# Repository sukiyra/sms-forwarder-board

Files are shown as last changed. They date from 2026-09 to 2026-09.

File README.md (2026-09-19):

# SMS Forwarder Board

面向 ESP32-C3 与 ML307 系列蜂窝模组的短信网关固件、Web 管理台和 Windows 批量量产工具。

这是由 [sukiyra](https://github.com/sukiyra) 独立维护和发布的工程仓库，GitHub 仓库本身不是 Fork。固件、管理台、设备自检协议、版本发布和量产流程在同一个仓库维护。

## 主要能力

- 自动识别 ML307A、ML307C、ML307R、ML307Y，并按模组能力选择短信上报方式。
- 国内版 ML307C 可在移动、联通、电信网络注册；本产品的短信收发只承诺中国移动和中国联通，电信网络仍可用于数据连接但界面会明确标记短信不可用。
- 支持实体 SIM 与 eSIM/eUICC；白卡初始化错误会自动容错，首页分别显示卡识别、短信配置和蜂窝注册状态。
- 接收和主动发送短信；短信使用固定 50 条循环存储，不会无限占用 Flash。
- 支持企业微信、飞书、Bark、电子邮件、钉钉、PushPlus、Server 酱、Gotify、Telegram 及自定义 HTTP 推送。
- 可扫描运营商、严格手动选网和恢复自动选网；目标网络拒绝时自动恢复可用网络。
- 初始化引导自动扫描附近 Wi-Fi，可选择网络、输入密码并在保存前测试连接；系统设置中也可随时更换主备网络。
- Wi-Fi 断线时自动保活并轮询主备网络；持续无法恢复会自动开启 `sms-forwarder` 热点进入手动配网。
- 人可读通知统一显示北京时间；开放 API 与本地记录继续使用 UTC ISO-8601，便于程序可靠解析和排序。
- 响应式 Web 管理台，适配手机、普通桌面和超宽屏；仪表盘并列显示蜂窝与 Wi-Fi 五级信号图，跨页面保留 OTA、选网、切卡和短信发送进度。
- 设备健康面板实时显示堆内存占用、启动以来最低余量、最大连续内存块、碎片率、LittleFS 占用、运行时间和上次复位原因；低内存、严重碎片或存储异常会标红。
- Windows 量产工具支持在线选择 GitHub Release 版本、多串口并行烧录和逐台验收。
- Windows 局域网发现工具可自动列出同网段设备，并一键打开对应管理页面。
- 支持从 GitHub Releases 在线检查和安装 OTA 更新；通过资产 API 绕过部分网络对 GitHub 下载页的连接限制，分段下载时持续回报字节数和进度，并使用双应用分区、HTTPS 证书校验、SHA-256 校验与启动失败自动回滚。
- 每台设备输出 CSV 与 JSON 量产记录，不记录短信正文、Wi-Fi 密码或推送密钥。

## 下载与烧录

打开仓库的 [Releases](https://github.com/sukiyra/sms-forwarder-board/releases)，每个版本提供三个压缩包和一个 OTA 固件：

- `sms-forwarder-firmware-vX.Y.Z.zip`：带 SHA-256 清单的 ESP32-C3 固件。
- `sms-forwarder-production-tool-windows-vX.Y.Z.zip`：Windows 单文件量产工具与 `esptool.exe`。
- `sms-forwarder-lan-scanner-windows-vX.Y.Z.zip`：自动发现局域网设备并打开管理台。
- `sms-forwarder-ota-vX.Y.Z.bin`：设备在线升级使用的应用镜像。

普通用户只需下载 Windows 工具包并解压：

1. 双击 `sms-forwarder-production-tool.exe`。
2. 在“GitHub 版本”中选择要烧录的版本。
3. 插入一块或多块设备，点击“刷新串口”。
4. 选择设备后开始烧录。
5. 只把显示 `PASS` 的设备作为通过品。

在线固件会缓存在 `%LOCALAPPDATA%\SMS Forwarder Production Tool\firmware`。工具会验证 Release 压缩包结构、清单版本和每个镜像的 SHA-256；断网时可以切换到本地固件目录。

## 局域网设备发现

升级到 v1.6.0 或更高版本后，解压并运行 `sms-forwarder-lan-scanner.exe`。工具会扫描电脑的 IPv4 局域网，列出设备 IP、固件版本、模组型号、OTA 能力、MAC 和设备 ID；双击设备即可打开管理台。

发现协议使用 UDP 37888 和每次扫描生成的随机 nonce。设备只回应同一子网请求，并限制回复频率。报文不包含手机号、ICCID、短信、Wi-Fi 密码、登录密码或推送密钥。路由器开启 AP 隔离或访客网络隔离时，设备之间无法互相发现。

## 支持的硬件

| 部件 | 要求 |
| --- | --- |
| 主控 | ESP32-C3，4 MB Flash |
| 开发板配置 | MakerGO ESP32 C3 SuperMini |
| 蜂窝模组 | ML307A / ML307C / ML307R / ML307Y AT 固件 |
| 串口 | ESP32 GPIO3 → ML307 RX；GPIO4 ← ML307 TX |
| 模组使能 | ESP32 GPIO5 → ML307 EN |
| 供电 | 需满足模组发射瞬时电流，主控与模组共地 |

不同 ML307 完整料号支持的频段和运营商不同。固件能够适配 AT 指令差异，但不能为硬件增加缺失的射频频段。采购和量产前必须按完整丝印、模组规格书、SIM 套餐及当地网络实测。

## 首次启动

设备没有可用 Wi-Fi 配置时会开启 `sms-forwarder` 配置热点。连接后访问 `http://192.168.4.1`，初始化引导会自动扫描附近网络；选择 Wi-Fi、输入密码并完成连接测试后保存。设备接入局域网后，通过路由器分配的 IP 打开管理台。

运行期间断线时，设备先使用 ESP32 自动重连保活。持续 2 分钟仍未恢复会按顺序非阻塞尝试最多 5 个已保存网络，每个网络最多等待 12 秒；全部失败后自动恢复 `sms-forwarder` 配置热点。此时重新连接热点即可修改 Wi-Fi，不需要清空其他系统配置。

默认管理员账号为 `admin`，初始密码为 `admin123`。首次登录后请立即在“系统设置”中修改密码。管理页面使用局域网 HTTP，不应直接映射到公网。

## 手动编译

需要 Arduino CLI、ESP32 Arduino Core 3.3.11，以及以下库：

- `pdulib@0.5.11`
- `ReadyMail@0.4.2`
- `ArduinoJson@7.4.2`

PowerShell：

```powershell
arduino-cli compile `
  --fqbn esp32:esp32:makergo_c3_supermini `
  --build-property upload.maximum_size=1966080 `
  --output-dir .\build `
  .\code
```

仓库内的 `code/partitions.csv` 定义 4 MB Flash 双应用分区：`app0` 与 `app1` 各 1,920 KB，并保留 NVS、OTA 状态、128 KB LittleFS 短信存储和 64 KB 崩溃转储分区。不要用 Arduino 菜单中的单应用分区覆盖它。

## 在线 OTA

在“系统设置 → 在线固件升级”中检查并安装正式版。设备只接受本仓库最新 GitHub Release 中名称为 `sms-forwarder-ota-vX.Y.Z.bin` 的资产，并验证以下条件：

- HTTPS 证书链有效，设备时间已通过 NTP 同步。
- 目标版本高于当前版本，不允许在线降级。
- 文件名称、Content-Length、Release 资产大小和备用分区容量一致。
- 下载完成后的 SHA-256 与 GitHub Release 资产摘要一致。
- ESP32 镜像头和写入完整性通过 Update/bootloader 校验。

固件始终写入非活动分区。下载中断、摘要不符或写入失败不会切换启动分区；新版本首次启动必须完成配置、WiFi、Web 服务和模组初始化，之后才会确认镜像。此前发生崩溃或看门狗复位时，bootloader 会回滚到旧版本。

短信记录固定为 50 条循环存储，系统日志固定为 80 条且每条最多 320 字节，运营商扫描、长短信和任务队列也使用固定容量。管理台的健康面板会保留 ESP32 自启动以来的最低空闲堆指标，用于发现缓慢泄漏；量产和长期运行仍应使用实际电源、SIM 与网络做持续老化测试。

从旧分区升级时，必须先用当前量产包通过 USB 完整烧录一次分区表。只写入应用 BIN 或从已装在旧分区上的 v1.6.3 在线升级，都会保留旧分区表，无法创建 LittleFS；管理台会明确显示“分区需迁移”。完成这次迁移后，后续版本可直接在线升级。需要保留现有配置时，在量产工具中关闭“全片擦除”；NVS 地址保持不变。

## 量产工具命令行

```powershell
# 查询 GitHub 可烧录版本
python .\factory\production_tool.py --list-versions

# 选择指定 Release，并烧录所有自动识别的 ESP32 串口
python .\factory\production_tool.py --all --version v1.6.0 --require-sim --require-network

# 使用最新 Release，保留设备已有配置
python .\factory\production_tool.py --ports COM3 --version latest --keep-data

# 只运行工厂自检
python .\factory\production_tool.py --ports COM3 --skip-flash --require-sim --require-network
```

更多操作见 [量产工具说明](factory/README.md)。协议与模块结构见 [开发文档](dev_doc/README.md)。

## 发布流程

推送 `v*` 标签会自动执行：

1. Python 与 C++ 测试。
2. 嵌入式 JavaScript 语法检查。
3. ESP32-C3 固件编译。
4. 固件清单、USB 烧录 ZIP 与 OTA 应用镜像打包。
5. Windows 单文件量产工具和局域网发现工具构建。
6. 创建 GitHub Release 并上传固件包、OTA 镜像、量产工具和局域网发现工具。

## 许可证与来源

固件、Web 管理台和量产工具使用 [MIT License](LICENSE)。新仓库由 sukiyra 独立维护；早期 MIT 代码的版权声明和来源记录保存在 [NOTICE](NOTICE) 中。提交修复和功能前请确保不包含 SIM 完整 ICCID、手机号、Wi-Fi 密码或推送密钥。

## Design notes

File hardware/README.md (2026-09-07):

# SMS Forwarder Board Rev 1.0

这是与本仓库固件配套的 USB 棒形短信转发硬件。主控为 ESP32-C3-MINI-1，蜂窝模组为 ML307A-DSLN；ML307A-DCLN 可作为不需要 GNSS 时的替代料。工程使用 KiCad 10 创建，制造文件按立创/JLCPCB 四层板工艺导出。

Rev 1.0 是等待首板验证的工程样板。KiCad 10.0.6 ERC 与 DRC 均为 0 错误、0 警告、0 未连接，但这不能替代实体板的电源瞬态、射频、热、SMT 焊接和运营商网络测试。建议先下单 5 块裸板、贴装 2 块，完成 [装配与验证步骤](ASSEMBLY.md) 后再量产。

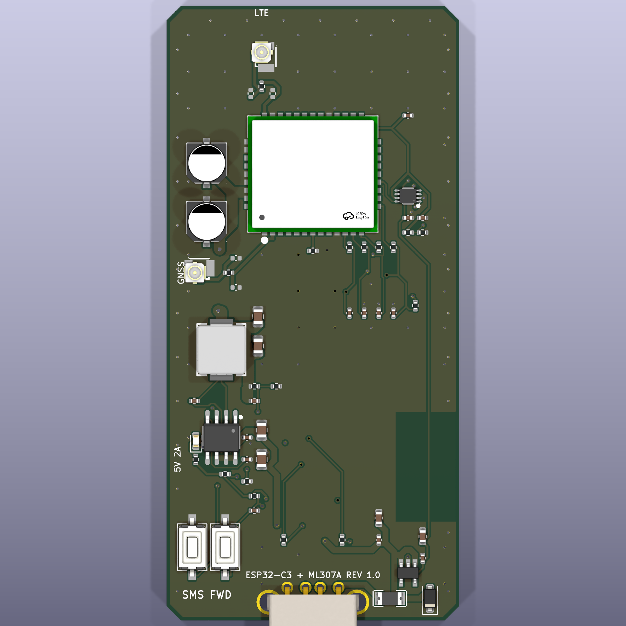
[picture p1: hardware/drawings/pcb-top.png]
PCB 正面


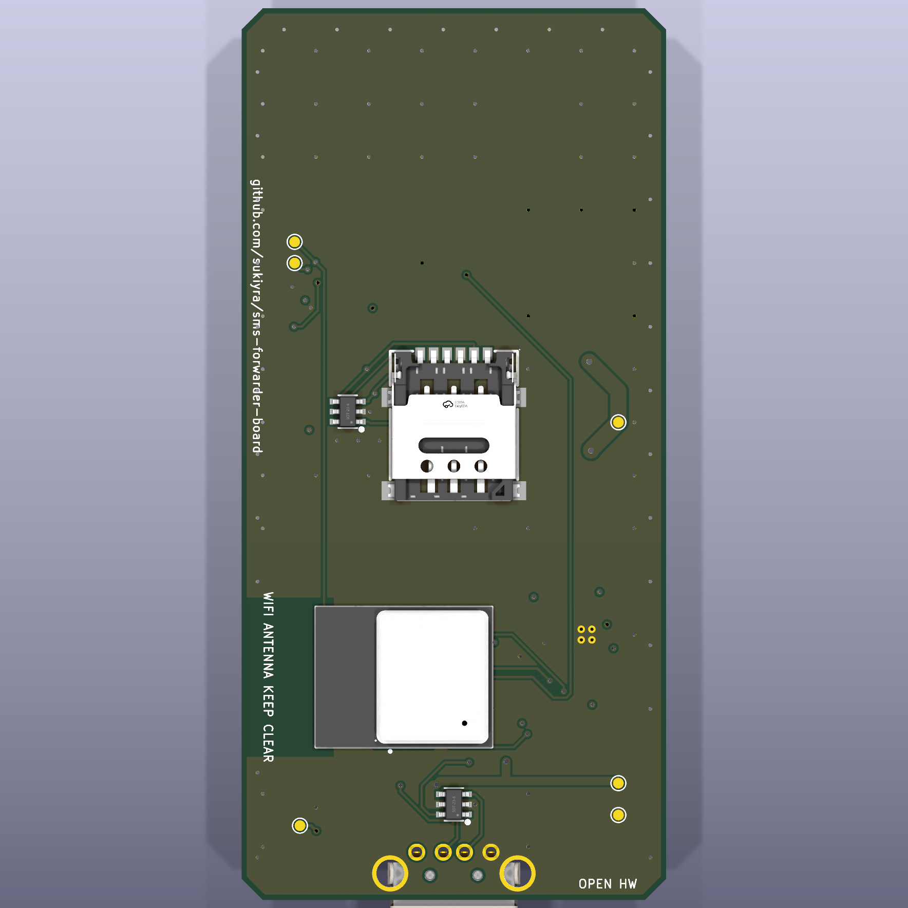
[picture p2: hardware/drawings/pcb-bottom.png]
PCB 背面


## 主要特性

- 40 mm × 84 mm 四层 PCB，USB-A 直插供电与原生 USB 下载。
- ESP32-C3 GPIO3/GPIO4 通过 TXU0202 与 ML307 的 1.8 V UART0 相连。
- ESP32-C3 GPIO5 控制 SY8205 的 EN，实现固件需要的模组硬断电重启。
- ML307 独立 3.816 V 同步降压电源，模组旁配置 2 × 220 µF 低 ESR 储能电容。
- Nano SIM 卡座、四路 SIM ESD、22 Ω 串联阻尼及 DATA 上拉。
- LTE MAIN 与可选 GNSS 两个 U.FL 接口，均预留 π 型匹配位。
- RESET、BOOT 按键和量产测试点。

## 文件目录

| 文件 | 用途 |
| --- | --- |
| `sms_forwarder_ml307a/` | KiCad 10 原理图、PCB、工程文件和 Specctra DSN |
| `libs/` | 项目专用符号、封装与 3D 模型 |
| `manufacturing/SMS-Forwarder-ML307A-Gerber.zip` | 可上传到立创下单页的 Gerber/钻孔压缩包 |
| `manufacturing/bom/BOM_JLCPCB.csv` | 立创 SMT BOM |
| `manufacturing/bom/BOM_Full.csv` | 含 DNP、手焊件与测试焊盘的完整 BOM |
| `manufacturing/bom/SMS-Forwarder-BOM.xlsx` | 便于采购、替代料和备注管理的 BOM |
| `manufacturing/pick-and-place/CPL_JLCPCB.csv` | JLC 标准列名的双面贴片坐标 |
| `drawings/schematic.pdf` | 原理图 PDF |
| `drawings/pcb-layout.pdf` | PCB 顶层装配图 |
| `tools/generate_hardware.py` | 重新生成器件布局、网表、DSN 与 BOM |

## 模组兼容性

本 PCB Rev 1.0 的焊盘仅适用于 **ML307A 94-pin 封装**。ML307C 与 ML307Y 使用 109-pin LCC+LGA 封装，虽然固件能够在运行时识别 A/C/Y 并选择兼容 AT 指令，但它们不能直接焊到本版 ML307A 焊盘上。C/Y 需要单独的 109-pin PCB 变体，不能通过软件解决封装差异。

这一区分也适用于量产：在贴片订单里必须把 `ML307A-DSLN / C5375091` 或 `ML307A-DCLN / C5362285` 与 PCB 版本绑定，不能让工厂按库存替换成 ML307C/Y。

## 立创下单参数

- 板层：4 层
- 板厚：1.6 mm
- 外层铜厚：1 oz
- 内层铜厚：0.5 oz
- 推荐叠层：JLC04161H-7628
- 阻抗：LTE/GNSS 走线按 50 Ω 单端复核；USB D+/D− 按 90 Ω 差分复核
- 表面处理：沉金 1U" 或无铅喷锡
- 阻焊/丝印：绿色/白色
- 最小信号线宽/间距：0.20/0.18 mm；局部接地扇出 0.15 mm
- 最小过孔：0.60/0.30 mm；模组电源过孔 1.00/0.50 mm
- 拼板：首轮不要拼板，先做 5 片工程样板

下单时选择与工程一致的阻抗叠层，并在阻抗计算器中重新确认最终线宽。立创可能调整材料批次或阻抗补偿，制造端给出的补偿值优先于工程中的名义线宽。

`BOM_JLCPCB.csv` 和 `CPL_JLCPCB.csv` 可直接用于 SMT 询价。USB-A 插头 J1 标为手焊件，RF 匹配电容 C23–C26 标为 DNP，测试点不会出现在贴片坐标中。立创导入后仍要逐项核对器件方向，特别是 U1、U2、J2、D1、D2、U3、U5、U6 和 U7。

## 供电要求

ML307 在 LTE 发射时会产生接近 2 A 的峰值电流。USB 电源必须能持续提供 5 V/2 A，并使用低阻 USB 接口或短延长线。普通电脑 USB 2.0 端口可能限流，表现为模组掉线、收不到短信、来电提示关机或反复注册。

板上 2 A 自恢复保险用于故障保护，不代表任意电脑 USB 端口都能提供 2 A。调试时应在 `TP1/+5V` 和 `TP2/+3V8_MODEM` 测量最低电压；模组发射期间 3.8 V 电源不能跌破 3.4 V。

## 首板验证

首批仅贴装 2 片，按 [装配与验证步骤](ASSEMBLY.md)逐项验收。通过电源纹波、UART、电流峰值、SIM、三网驻网、收发短信、Wi-Fi 和 24 小时压力测试后，再放开批量贴片。

## 重新生成

安装 KiCad 10 后运行 `hardware/tools/generate_hardware.py` 可重新生成放置完成的 PCB、DSN 和 CSV BOM。使用 Freerouting 1.6.5 对 DSN 布线后，以 `hardware/tools/import_freerouting.py` 导回 KiCad，再运行 `hardware/tools/generate_schematic.py` 和 KiCad CLI 导出制造资料。仓库内提交的 `.kicad_pcb` 已包含最终布线，不需要为了下单重新运行生成脚本。

## 许可证

`hardware/` 下的硬件源文件与制造资料使用 [CERN-OHL-P-2.0](LICENSE-CERN-OHL-P-2.0.txt)。仓库其余固件和量产工具继续使用根目录 MIT License。

## 设计依据

- [Espressif ESP32-C3 硬件设计指南](https://documentation.espressif.com/esp-hardware-design-guidelines/en/latest/esp32c3/index.html)
- [ESP32-C3-MINI-1/-1U 数据手册](https://documentation.espressif.com/esp32-c3-mini-1_datasheet_en.html)
- [JLCPCB 四层阻抗叠层](https://jlcpcb.com/impedance)
- ML307A Hardware Design Manual V1.0.1（仓库不再分发供应商手册；请从模组供应商取得当前版本）

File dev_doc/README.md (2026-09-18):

# 短信转发器 (SMS Forwarding) — 项目总览

## 项目简介

基于 **ESP32-C3 (MakerGO SuperMini)** 的短信转发设备。通过 4G/LTE 模组接收短信，经由 WiFi 网络将短信内容推送到邮件和多种即时通讯平台（微信/钉钉/飞书/Telegram 等）。提供 Web 管理界面进行配置和诊断。

现场故障与已验证处理方法统一记录在 [troubleshooting.md](troubleshooting.md)。

## 硬件平台

| 组件 | 型号 / 规格 |
|---|---|
| MCU | ESP32-C3 (MakerGO SuperMini) |
| 4G 模组 | 通过 UART 连接，AT 指令控制 |
| 模组 EN 引脚 | GPIO 5 |
| 模组 TXD/RXD | GPIO 3 / GPIO 4 |
| LED | GPIO 8（内置 LED） |
| 串口波特率 | USB: 115200, 模组: 115200 |

## 第三方依赖库

| 库 | 版本 | 用途 |
|---|---|---|
| pdulib | 0.5.11 | PDU 格式短信编解码 |
| ReadyMail | 0.4.2 | SMTP 邮件发送 |
| Arduino ESP32 Core | 3.3.11 | WiFi / HTTP / mbedTLS / NTP |

## 核心功能

1. **短信接收** — 4G 模组 PDU 模式自动上报，解析后提取发送方、设备接收时间、接收 Profile 与内容
2. **长短信合并** — 支持多段长短信（最多 10 段）自动拼合，30 秒超时保护
3. **多通道推送** — 同时支持最多 5 个推送通道，可独立配置推送到不同平台
4. **邮件通知** — 通过 SMTP 发送通知邮件（QQ 邮箱等）
5. **Web 管理** — 单页应用 (SPA)，侧边栏导航 + HTTP Basic Auth 保护
6. **系统日志** — Web 端实时查看设备串口日志，自动刷新，最多保留 80 行且单行最多 320 字节
7. **管理员命令** — 通过短信远程执行 SMS:发送 和 RESET 命令（仅限管理员号码）
8. **号码黑名单** — 支持按号码过滤骚扰短信

## 支持推送平台

| 类型 | 枚举值 | 说明 |
|---|---|---|
| POST JSON | `PUSH_TYPE_POST_JSON` (1) | 通用 POST JSON，字段: sender / message / timestamp |
| Bark | `PUSH_TYPE_BARK` (2) | iOS 推送，字段: title / body |
| GET 请求 | `PUSH_TYPE_GET` (3) | 参数放在 URL query string |
| 钉钉机器人 | `PUSH_TYPE_DINGTALK` (4) | 支持加签安全验证 |
| PushPlus | `PUSH_TYPE_PUSHPLUS` (5) | 微信公众号推送，支持多渠道 |
| Server酱 | `PUSH_TYPE_SERVERCHAN` (6) | 微信推送 |
| 自定义模板 | `PUSH_TYPE_CUSTOM` (7) | 用户自定义 HTTP 请求体 |
| 飞书机器人 | `PUSH_TYPE_FEISHU` (8) | 支持签名验证 |
| Gotify | `PUSH_TYPE_GOTIFY` (9) | 自建推送服务 |
| Telegram | `PUSH_TYPE_TELEGRAM` (10) | Bot API |
| 企业微信机器人 | `PUSH_TYPE_WECOM` (11) | 群机器人 Webhook，支持可选关键词 |

## 工程结构

```
code/
├── code.ino              # 入口: setup() + loop()
├── config_types.h        # 枚举/结构体/常量定义（无依赖）
├── globals.h / .cpp      # 全局变量 + 引脚定义 + 公共头文件
├── config.h / .cpp       # NVS 配置存取、配置校验
├── auth.h / .cpp         # Cookie 会话、CSRF 防护、登录限流
├── api_handlers.h / .cpp # 状态、短信、eSIM、运营商与配置 API
├── modem.h / .cpp        # 模组 AT 指令、电源控制、短信发送
├── push.h / .cpp         # 多通道推送、邮件通知、加密工具函数
├── sms_process.h / .cpp  # 短信解析、长短信合并、黑名单、管理员命令
├── sms_store.h / .cpp    # LittleFS 短信持久化与收件箱
├── esim_manager.h / .cpp # eUICC Profile 枚举、切换任务、EID 读取与删除（通道三级降级）
├── operator_manager.*    # 异步扫描、手动选网与自动选网任务
├── web_handlers.h / .cpp # HTTP 请求处理器 + 日志环形缓冲区
├── web_html.h / .cpp     # SPA HTML 页面模板（单页 10 个面板）
├── discovery.h / .cpp    # UDP 37888 局域网设备发现
├── ota_manager.h / .cpp  # GitHub Release 在线升级、摘要校验与回滚确认
├── ota_policy.h / .cpp   # 可在主机测试的版本与资产校验策略
└── partitions.csv        # 4 MB Flash 双 OTA 分区表
```

## 编译与烧录

```powershell
# 编译
arduino-cli compile --fqbn esp32:esp32:makergo_c3_supermini --build-property upload.maximum_size=2031616 --output-dir ".\build" ".\code"

# 烧录
arduino-cli upload --fqbn esp32:esp32:makergo_c3_supermini --port COM3 --input-dir ".\build" ".\code"

# 串口监视
arduino-cli monitor --port COM3 --config 115200
```

## 启动流程

1. 初始化 GPIO（LED、模组 EN 引脚）
2. 启动 USB Serial (115200) 和模组 Serial1 (115200, GPIO 3/4)
3. 模组断电重启（EN 引脚控制）
4. 加载 NVS 配置并挂载 LittleFS 短信存储
5. 连接 Wi-Fi，启动 HTTP 管理台并同步 NTP 时间
6. 若配置有效，发送启动通知邮件
7. 模组初始化：AT 握手 → 禁用数据连接 → 读取并脱敏缓存 ICCID 尾号 → 配置短信 URC 上报 → 设置 PDU 模式 → 等待网络注册
8. 启动 eSIM 与运营商状态管理任务

## 主循环

```
loop()
  ├── server.handleClient()     // HTTP 请求处理
  ├── 配置无效时每秒打印 IP
  ├── checkConcatTimeout()      // 长短信超时检查
  ├── Serial → Serial1 透传    // USB → 模组 AT 透传
  └── checkSerial1URC()        // 模组 URC 解析（短信上报）
```

## 关键设计决策

- **PDU 模式** 而非 Text 模式：中文短信必须使用 PDU 编码
- **CGACT 默认关闭**：启动时主动禁用 4G 数据连接，避免意外流量消耗（Ping 功能会临时激活）
- **NVS 持久化**：所有配置存储在 ESP32 非易失存储中，断电不丢失
- **单页应用 (SPA)**：Web UI 采用侧边栏 + 面板切换，所有功能在一个 HTML 页面中，通过 JS 切换可见面板
- **日志行缓冲**：`logCapture()` 将输出追加到行缓冲区，仅 `logCaptureLn()` 提交整行到环形缓冲区，避免非换行输出被误拆成多行
- **日志环形缓冲区**：80 行容量、单行 320 字节上限，循环覆盖，通过 `/log` 端点以 JSON 返回，Web 端每 2 秒自动刷新
- **模块化设计**：每个 .h/.cpp 对承担单一职责，便于增减功能和问题定位
- **HTML 模板分离**：HTML 字符串常量单独存于 `web_html.cpp`，便于 UI 修改而不影响逻辑代码

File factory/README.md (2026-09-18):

# Windows 批量量产工具

量产工具用于在线选择 GitHub Release 固件、并行烧录多块 ESP32-C3，并通过 USB 工厂协议验收 ESP32、ML307、SIM、短信配置和蜂窝注册。空板默认使用无卡硬件验收；插入测试卡后可额外要求短信和驻网通过。国内版 ML307C 使用电信网络时，“有卡验收：要求短信就绪”会判定短信能力不合格；移动和联通可正常进入短信验收。

## 直接使用发布包

1. 从 [GitHub Releases](https://github.com/sukiyra/sms-forwarder-board/releases) 下载 `sms-forwarder-production-tool-windows-vX.Y.Z.zip`。
2. 解压整个压缩包。
3. 双击 `sms-forwarder-production-tool.exe`。
4. 等待“GitHub 版本”下拉框加载，选择要量产的版本。
5. 插入设备并刷新串口，可一次多选并行烧录。
6. 新焊空板保持两个“有卡验收”选项不勾选；需要测试 SIM、短信和驻网时，插入测试卡后再勾选相应项目。
7. 点击“开始所选设备”，只接收显示 `PASS` 的设备。

无卡硬件验收仍会检查 ESP32-C3、Flash 烧录、固件工厂协议、USB 串口和 ML307 完整型号。未插 SIM 时不会把短信接口、运营商和蜂窝注册列为失败项，也不会掩盖主控或模组识别故障。

工具从 `sukiyra/sms-forwarder-board` 的 Releases 下载包含 `firmware` 的 ZIP。下载后会校验压缩包路径、版本号、ESP32-C3 芯片类型以及清单内每个镜像的 SHA-256。

下载缓存位于：

```text
%LOCALAPPDATA%\SMS Forwarder Production Tool\firmware
```

GitHub 暂时不可用时，选择“本地固件目录”即可离线烧录。

## OTA 分区迁移

v1.6.3 起使用两个 1,920 KB 应用分区，并保留 128 KB LittleFS 与 64 KB 崩溃转储，支持管理台在线升级和启动失败回滚。旧分区版本必须先通过本工具完整写入一次 v1.6.3 或更高版本；仅上传应用 BIN 无法更新分区表。

迁移时需要保留 WiFi、推送和登录配置，可关闭“全片擦除”。NVS 的地址和大小没有变化。量产新板仍建议开启全片擦除。

## 擦除策略

- 开启“全片擦除”：清除旧 Wi-Fi、推送配置和短信记录，适合正式出厂。
- 关闭“全片擦除”：保留数据分区，适合返修或固件升级。

## 量产记录

记录保存在程序目录的 `records` 文件夹：

- `production.csv`：一行一台，可用 Excel 打开。
- 独立 JSON：保留该设备完整工厂自检结果。

记录包含芯片 ID、固件版本、ML307 完整料号、SIM 类型、ICCID 尾号和网络 PLMN，不包含短信正文、Wi-Fi 密码或推送密钥。

## 从源码启动

```powershell
.\factory\start.ps1
```

首次运行会安装固定版本的 `pyserial`。

## 命令行

```powershell
# 列出串口
.\factory\start.ps1 --list

# 列出 GitHub 版本
.\factory\start.ps1 --list-versions

# 在线选择指定版本量产
.\factory\start.ps1 --all --version v1.6.0 --require-sim --require-network

# 在线选择最新版本并保留配置
.\factory\start.ps1 --ports COM3 COM4 --version latest --keep-data

# 使用本地固件目录
.\factory\start.ps1 --ports COM3 --firmware-dir .\factory\dist

# 只验收已烧录空板（无需 SIM）
.\factory\start.ps1 --ports COM3 --skip-flash

# 只验收已烧录设备，并要求 SIM、短信和驻网通过
.\factory\start.ps1 --ports COM3 --skip-flash --require-sim --require-network
```

可用 `--github-repo owner/repository` 指定其他兼容仓库；Release 必须包含固件 ZIP，压缩包内必须有唯一的 `manifest.json`。

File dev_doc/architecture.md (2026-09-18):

# 系统架构

## 模块依赖关系

```
                    ┌─────────────────────┐
                    │    config_types.h    │  (枚举/结构体/常量，无依赖)
                    └─────────┬───────────┘
                              │
                    ┌─────────▼───────────┐
                    │     globals.h       │  (全局变量声明 + 公共头文件)
                    │     globals.cpp     │  (全局变量定义)
                    └─────────┬───────────┘
                              │
        ┌─────────┬───────────┼───────────┬───────────┐
        │         │           │           │           │
   ┌────▼───┐ ┌───▼────┐ ┌───▼────┐ ┌───▼────┐ ┌───▼────┐
   │config  │ │ modem  │ │ push   │ │sms_prc │ │web_hdl │
   │.h/.cpp │ │.h/.cpp │ │.h/.cpp │ │.h/.cpp │ │.h/.cpp │
   └────────┘ └───┬──┬─┘ └───┬─┬──┘ └───┬────┘ └───┬────┘
                  │  │       │ │        │          │
                  │  └───────┼─┼────────┘    ┌─────┘
                  │          │ └─────────────┘
                  │    ┌─────▼──────┐    ┌───▼────┐
                  │    │sms_process │    │web_html│
                  │    │  .h/.cpp   │    │.h/.cpp │
                  │    └────────────┘    └────────┘
         ┌────────▼─────────┐
         │    code.ino      │  (入口: setup + loop)
         │ (NVS)  │
         └──────────────────┘
```

箭头方向 = `#include` 依赖方向。`config_types.h` 是最底层，`code.ino` 是最顶层。

## 数据流总览

### 短信接收流程

```
4G模组 UART
    │
    ▼
checkSerial1URC()          [sms_process.cpp]
    │  逐行读取 Serial1
    │  识别 "+CMT:" 头
    │  接收 PDU hex 数据
    ▼
pdu.decodePDU()            [pdulib 库]
    │  提取 sender / SCTS / text
    │  提取长短信 concatInfo (refNumber, partNumber, totalParts)
    ▼
┌─[长短信? totalParts > 1]─┐
│                           │
▼ 是                     ▼ 否 (普通短信)
findOrCreateConcatSlot()    │
  → 缓存分段                │
  → 收齐后合并              │
  → assembleConcatSms()     │
         │                  │
         └──────┬───────────┘
                ▼
         processSmsContent()
           ├── 记录设备接收时间 + 接收 Profile 脱敏标签
           ├── isInNumberBlackList()? → 忽略
           ├── isAdmin()? → processAdminCommand()
           │                  ├── "SMS:号码:内容" → sendSMS()
           │                  └── "RESET" → resetModule() + ESP.restart()
           ├── sendSMSToServer()     [push.cpp]
           │     └── sendToChannel() × N
           └── sendEmailNotification()  [push.cpp]
```

### HTTP 请求流程

```
浏览器 (SPA 单页应用)
    │  侧边栏切换面板，所有功能在一个 HTML 页面
    │  JS 控制 panel 可见性，无需页面跳转
    ▼
server.handleClient()     [code.ino loop]
    │
    ▼
checkAuth()               [web_handlers.cpp]
    │  HTTP Basic Auth
    │  账号: config.webUser
    │  密码: config.webPass
    ▼
路由分发:
    GET  /         → handleRoot()        SPA 主页 (HTML 模板变量替换，含 10 个面板)
    GET  /tools    → handleRoot()        兼容旧链接，返回同一 SPA 页面
    GET  /sms      → handleRoot()        兼容旧链接，返回同一 SPA 页面
    GET  /api/status → handleApiStatus()  读取缓存的设备/SIM/蜂窝信号状态
    POST /save     → handleSave()        保存配置 → saveConfig() → 发邮件
    POST /sendsms  → handleSendSms()     网页发送短信 → sendSMS()
    POST /ping     → handlePing()        AT+CGACT=1 → MPING → AT+CGACT=0
    GET  /query    → handleQuery()       查询 ATI/CESQ/ICCID/CEREG 等
    GET  /flight   → handleFlightMode()  AT+CFUN 查询/切换飞行模式
    GET  /at       → handleATCommand()   透传 AT 指令到模组
    GET  /log      → handleLog()         返回环形缓冲区日志 (JSON 数组)
```

### 蜂窝信号采集

`simManagerLoop()` 在 SIM 与短信服务就绪后，每 10 秒异步发送一次
`AT+CESQ`。解析后的 LTE RSRP/RSRQ 保存在内存中，`GET /api/status`
只读取缓存，不会因网页每 3 秒轮询而占用短信 UART。缓存超过 45 秒，或 SIM
拔出/状态失效后，接口返回未知信号。

### 日志系统架构

```
业务代码调用:
    logCapture("目标号码: ");       → Serial.print() + 追加到 _logLine
    logCaptureLn(String(phone));    → Serial.println() + 提交 _logLine 到环形缓冲区
    logCaptureF("ref=%d\n", ref);    → Serial.print() + 以 \n 结尾时自动提交整行
         │
         ▼
    _logLine (行缓冲区)              // 累积 logCapture 调用直到 logCaptureLn 或 \n
         │
         ▼  logCaptureLn / logCaptureF(\n)
    _logAppend()                    // 写入环形缓冲区
         │
         ▼
    logBuffer[120]                  // 环形缓冲区，循环覆盖
         │
         ▼
    handleLog()                     // GET /log → JSON ["line1","line2",...]
         │
         ▼
    Web 日志面板                   // 每 2 秒自动轮询，终端风格深色主题
```

### 配置持久化流程

```
Web 表单提交 /save
    │
    ▼
handleSave()
    │  解析 POST 参数
    │  赋值到 config 全局结构体
    ▼
saveConfig()              [config.cpp]
    │  Preferences(NVS) 写入
    │  namespace: "sms_config"
    ▼
configValid = isConfigValid()  重新校验
    │
    ▼
sendEmailNotification()   发送 "配置已更新" 邮件
```

## 线程/任务模型

单线程事件循环（标准 Arduino 模型），所有操作在主 loop 中串行执行：

| 操作 | 频率 | 超时保护 |
|---|---|---|
| HTTP 请求处理 | 每帧 | 无（非阻塞） |
| 长短信超时检查 | 每帧 | 30s 超时自动转发不完整消息 |
| Serial→Serial1 透传 | 每帧 | 无（单字节读） |
| Serial1 URC 检查 | 每帧 | 逐行读取，无行则立即返回 |
| 配置无效告警 | 每秒 | 仅 configValid=false 时 |

## 内存管理

- ESP32-C3 可用内存：~327KB
- 全局变量占用：~43KB
- PDU 缓冲区：4096 字节（`pdu = PDU(4096)`）
- 长短信缓存：5 组 × 10 段，每段内容动态分配（`String`）
- 日志环形缓冲区：80 行 × String，单行硬上限 320 字节
- 日志行缓冲区：1 个有界 String（`_logLine`），用于合并 logCapture 输出
- 串口行缓冲：500 字节（`SERIAL_BUFFER_SIZE`）
- HTTP 响应在函数内栈分配，调用结束自动释放
- `/api/status` 报告当前/历史最低堆、最大连续块、碎片率、LittleFS 占用与复位原因；`health_policy` 使用固定阈值统一输出健康等级

## 关键硬件引脚

| 定义 | GPIO | 功能 |
|---|---|---|
| `TXD` | 3 | 模组 UART TX |
| `RXD` | 4 | 模组 UART RX |
| `MODEM_EN_PIN` | 5 | 模组 EN 使能（LOW=关机, HIGH=开机） |
| `LED_BUILTIN` | 8 | 板载 LED（LOW=亮） |

## 错误处理策略

- **模组 AT 无响应**：重试（最多 10 次），LED 闪烁指示
- **WiFi 连接失败**：阻塞等待，LED 闪烁
- **NTP 同步失败**：记录日志，后续推送使用设备时间
- **HTTP 推送失败**：记录错误码和响应内容，不重试（避免卡顿）
- **PDU 解析失败**：记录日志，丢弃该条短信
- **长短信超时**：强制转发已收到的分段（标记缺失段）
- **配置无效**：每秒打印设备 IP 提示用户配置

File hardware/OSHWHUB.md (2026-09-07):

# 立创开源平台发布资料

## 项目标题

SMS Forwarder Board：ESP32-C3 + ML307A 4G 短信转发板

## 简介

一块 USB 棒形的 ESP32-C3 + ML307A Cat.1 短信转发器硬件。板上集成独立 3.8 V 同步降压模组电源、1.8 V UART 电平转换、Nano SIM、LTE/GNSS U.FL、USB 原生烧录与量产测试点，可直接运行本仓库的短信转发固件。

## 说明

本项目从器件数据手册与现有固件接口重新设计，提供 KiCad 源文件、Gerber、BOM、坐标文件、装配与首板验证说明。Rev 1.0 只适配 ML307A 94-pin 封装；ML307C/Y 为 109-pin 封装，需要单独 PCB 变体。

建议首轮打 5 片、只贴 2 片。ML307 发射峰值接近 2 A，必须使用 5 V/2 A 电源；普通电脑 USB 2.0 口限流时会导致掉网和短信异常。

当前 Rev 1.0 已通过 KiCad ERC/DRC，但尚未完成实体首板验证。发布状态应标记为“工程样板/待验证”，实体测试通过前不要标记为量产验证完成。

## 发布附件

- `sms_forwarder_ml307a.kicad_sch`、`sms_forwarder_ml307a.kicad_pcb`、`sms_forwarder_ml307a.kicad_pro`
- `SMS-Forwarder-ML307A-Gerber.zip`
- `BOM_JLCPCB.csv`、`BOM_Full.csv`、`SMS-Forwarder-BOM.xlsx`
- `CPL_JLCPCB.csv`
- `schematic.pdf`、`pcb-layout.pdf`、`pcb-top.png`、`pcb-bottom.png`
- `ASSEMBLY.md`、`NOTICE`、`LICENSE-CERN-OHL-P-2.0.txt`

## PCB 参数

40 × 84 mm、4 层、1.6 mm、外层 1 oz、内层 0.5 oz，推荐 JLC04161H-7628。最小孔 0.60/0.30 mm。LTE/GNSS 按 50 Ω 单端、USB 按 90 Ω 差分在下单阻抗计算器复核。

## 开源协议

CERN Open Hardware Licence Version 2 – Permissive（CERN-OHL-P-2.0）

## 标签

ESP32-C3、ML307A、Cat.1、短信转发、4G、Nano SIM、开源硬件、KiCad

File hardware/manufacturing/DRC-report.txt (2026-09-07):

** Drc report for sms_forwarder_ml307a.kicad_pcb **
** Created on 2026-09-07T19:52:12 **
** Report includes: Errors, Warnings **

** Found 0 DRC violations **

** Found 0 unconnected pads **

** Found 0 Footprint errors **

** Ignored checks **
    - Footprint has no courtyard defined
    - Track endpoint not centered on via
    - Tuning profile track geometries
    - Footprint doesn't match symbol's footprint filters
    - Footprint component type doesn't match footprint pads

** End of Report **

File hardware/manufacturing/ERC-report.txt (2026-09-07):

ERC report (2026-09-07T19:52:00, Encoding UTF8)
Report includes: Errors, Warnings

***** Sheet /

 ** ERC messages: 0  Errors 0  Warnings 0

 ** Ignored checks:
    - Global label only appears once in the schematic
    - Four connection points are joined together
    - SPICE model issue
    - Assigned footprint doesn't match footprint filters

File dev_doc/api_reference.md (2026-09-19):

# API 参考手册 — 完整函数索引

---

## 模块: config.cpp — 配置管理

### `void saveConfig()`
**用途**: 将 `config` 全局结构体所有字段写入 NVS。

**NVS Namespace**: `"sms_config"`
**写入模式**: `false`（读写模式）

**写入的 Key 列表**:
| NVS Key | 类型 | 对应字段 |
|---|---|---|
| `smtpServer` | String | `config.smtpServer` |
| `smtpPort` | Int | `config.smtpPort` |
| `smtpUser` | String | `config.smtpUser` |
| `smtpPass` | String | `config.smtpPass` |
| `smtpSendTo` | String | `config.smtpSendTo` |
| `adminPhone` | String | `config.adminPhone` |
| `webUser` | String | `config.webUser` |
| `webPass` | String | `config.webPass` |
| `numBlkList` | String | `config.numberBlackList` |
| `push{i}en` | Bool | 通道 i 是否启用 |
| `push{i}type` | UChar | 通道 i 推送类型 |
| `push{i}url` | String | 通道 i URL |
| `push{i}name` | String | 通道 i 名称 |
| `push{i}k1` | String | 通道 i 参数1 |
| `push{i}k2` | String | 通道 i 参数2 |
| `push{i}body` | String | 通道 i 自定义模板 |

---

### `void loadConfig()`
**用途**: 从 NVS 加载所有配置到 `config` 结构体。包含旧版本迁移逻辑。

**兼容迁移**: 如果存在旧 key `httpUrl` 且第一个推送通道未启用，自动迁移到通道 1。

**默认值**:
- `smtpPort`: 465
- `webUser`: `"admin"` (`DEFAULT_WEB_USER`)
- `webPass`: `"admin123"` (`DEFAULT_WEB_PASS`)
- 通道名称: `"通道1"` ~ `"通道5"`
- 通道类型: `PUSH_TYPE_POST_JSON` (1)

---

### `bool isPushChannelValid(const PushChannel& ch)`
**用途**: 检查单个推送通道配置是否完整可用。

**校验规则**:

| 推送类型 | 必填字段 |
|---|---|
| POST_JSON / BARK / GET / DINGTALK / FEISHU / CUSTOM | `url` 非空 |
| PUSHPLUS / SERVERCHAN | `key1` 非空 |
| GOTIFY | `url` 非空 **且** `key1` 非空 |
| TELEGRAM | `key1` 非空 **且** `key2` 非空 |

**前提**: `ch.enabled == true`，否则直接返回 false。

---

### `bool isConfigValid()`
**用途**: 检查系统是否有至少一种可用的通知方式。

**返回 true 条件**: 邮件配置完整（4 个 SMTP 字段均非空）**或** 至少一个推送通道通过 `isPushChannelValid()` 校验。

---

### `String getDeviceUrl()`
**返回**: `"http://{WiFi.localIP}/"`

---

## 模块: modem.cpp — 模组控制

### `String sendATCommand(const char* cmd, unsigned long timeout)`
**参数**:
- `cmd`: AT 指令字符串（不含 `\r\n`，函数自动追加）
- `timeout`: 等待超时（毫秒）

**行为**:
1. 清空 Serial1 缓冲区
2. 发送 `cmd\r\n`
3. 等待直到收到 "OK" 或 "ERROR" 或超时
4. 收到 OK/ERROR 后额外 `delay(50)` 读取剩余数据

**返回**: 模组完整响应字符串（含 OK/ERROR）

---

### `void modemPowerCycle()`
**行为**:
1. 配置 `MODEM_EN_PIN` 为输出
2. 拉低 1200ms → 关闭模组
3. 拉高 6000ms → 开启模组并等待启动

**注意**: 调用后需清空 Serial1 缓冲区（该函数不自动清空）

---

### `void resetModule()`
**行为**:
1. 调用 `modemPowerCycle()`
2. 清空 Serial1
3. 循环 10 次尝试 `sendATandWaitOK("AT", 1000)`
4. 打印恢复结果

---

### `bool sendATandWaitOK(const char* cmd, unsigned long timeout)`
**与 sendATCommand 区别**: 仅返回 true/false，不做额外 delay。用于初始化流程中的幂等检查。

---

### `bool waitCEREG()`
**用途**: 轮询 `AT+CEREG?` 直到网络注册成功。

**注册状态码**:
- `1`: 已注册本地网络 → true
- `5`: 已注册漫游 → true
- `0,2,3,4`: 未注册 → false

**超时**: 单次轮询 2000ms（调用方在外层循环调用）

---

### `void blink_short(unsigned long gap_time = 500)`
**行为**: LED 亮 50ms → 灭 → 等待 `gap_time` ms。

---

### `bool sendSMS(const char* phoneNumber, const char* message)`
**流程**:
1. `pdu.setSCAnumber()` 使用默认短信中心
2. `pdu.encodePDU(phoneNumber, message)` 编码
3. 发送 `AT+CMGS=<pduLen>`
4. 等待 `>` 提示符（5 秒超时）
5. 发送 PDU 数据 + `Ctrl+Z` (0x1A)
6. 等待 OK/ERROR（30 秒超时）

**返回**: true=成功, false=PDU编码失败/无提示符/ERROR/超时

---

## 模块: push.cpp — 推送与邮件

### `void sendEmailNotification(const char* subject, const char* body)`
**前提检查**: SMTP 四个字段均非空，否则打印跳过日志。

**实现**:
1. 创建 `smtp.connect(server, port, callback)`
2. `smtp.authenticate(user, pass, readymail_auth_password)`
3. 构造 `SMTPMessage`，设置 from/to/subject/body/timestamp
4. `smtp.send(msg)`

**from 格式**: `"sms notify <user@example.com>"`
**to 格式**: `"your_email <receiver@example.com>"`
**timestamp**: 使用 `time(nullptr)`（需 NTP 已同步）

---

### `void sendSMSToServer(const char* sender, const char* message, const char* timestamp)`
**行为**:
1. 检查 WiFi 连接
2. 检查是否有启用的有效通道
3. 遍历所有通道，对每个有效通道调用 `sendToChannel()`
4. 通道间 delay(100ms)

---

### `void sendToChannel(const PushChannel& channel, const char* sender, const char* message, const char* timestamp)`
**核心推送函数**。根据 `channel.type` 分发到 10 种推送方式之一。每个 case 构建对应的 HTTP 请求（URL/Header/Body），使用 `HTTPClient` 发送，打印响应码和内容。

**签名相关**:
- 钉钉: `HMAC-SHA256(timestamp+"\n"+secret)` → Base64 → URLEncode → 追加到 URL
- 飞书: `HMAC-SHA256(timestamp+"\n"+secret)` → Base64 → 放入 JSON body

**占位符**: 自定义模板（PUSH_TYPE_CUSTOM）支持 `{sender}` `{message}` `{timestamp}` 占位符替换。

---

### `String urlEncode(const String& str)`
标准 URL 编码（空格 → `+`, 非字母数字 → `%XX`）

---

### `String jsonEscape(const String& str)`
JSON 字符串转义：`"` → `\"`, `\` → `\\`, `\n` → `\\n`, `\r` → `\\r`, `\t` → `\\t`

---

### `String dingtalkSign(const String& secret, int64_t timestamp)`
HMAC-SHA256(timestamp + "\n" + secret, secret) → Base64 → URLEncode

---

### `int64_t getUtcMillis()`
通过 `gettimeofday()` 获取 UTC 毫秒级时间戳，失败则回退 `time(nullptr) * 1000`

---

## 模块: sms_process.cpp — 短信处理

### `void initConcatBuffer()`
将 `concatBuffer[MAX_CONCAT_MESSAGES]` 全部标记为未使用，清空所有分段。

---

### `int findOrCreateConcatSlot(int refNumber, const char* sender, int totalParts)`
**查找逻辑**:
1. 遍历缓冲区，找已用且 refNumber+sender 匹配的槽位 → 直接返回
2. 遍历缓冲区，找未使用槽位 → 初始化并返回
3. 无空闲槽位 → 覆盖最老的槽位（按 firstPartTime 比较）

---

### `String assembleConcatSms(int slot)`
按顺序拼接 `concatBuffer[slot].parts[0..totalParts-1]`，缺失分段标记 `[缺失分段N]`

---

### `void clearConcatSlot(int slot)`
将该槽位所有字段复位。

---

### `void checkConcatTimeout()`
遍历所有使用中的槽位，若 `millis() - firstPartTime >= 30000ms`，强制合并转发不完整消息，并清空槽位。

---

### `String readSerialLine(HardwareSerial& port)`
逐字节读取串口，遇 `\n` 返回行，`\r` 跳过，超长行保护（超过 SERIAL_BUFFER_SIZE 归零），无完整行返回空串。

**注意**: 使用 `static` 缓冲区，仅适合单线程调用。

---

### `bool isHexString(const String& str)`
检查字符串是否全为十六进制字符 `[0-9A-Fa-f]`。

---

### `bool isInNumberBlackList(const char* sender)`
**匹配逻辑**: 逐行读取 `config.numberBlackList`（换行符分隔），支持 `+86` 前缀的模糊匹配：
- `+8613800138000` 匹配黑名单中的 `13800138000`
- `13800138000` 匹配黑名单中的 `+8613800138000`

---

### `bool isAdmin(const char* sender)`
比较发送者与 `config.adminPhone`，忽略 `+86` 前缀差异。

---

### `void processAdminCommand(const char* sender, const char* text)`
**支持命令**:
| 命令格式 | 行为 |
|---|---|
| `SMS:号码:内容` | 调用 `sendSMS()` 代发短信，邮件通知结果 |
| `RESET` | 发送通知邮件 → `resetModule()` → `ESP.restart()` |

---

### `bool processSmsContent(const char* sender, const char* text, const char* timestamp)`

`timestamp` 对新短信为设备收到首个 PDU 分段时生成的 UTC ISO-8601 时间；NTP 不可用时回退为短信中心 SCTS。企业微信等面向用户的通知文本会转换为北京时间，API 字段仍保留原始时间。接收卡来源优先使用当前 Profile 名称与脱敏 ICCID 尾号；Profile 缓存尚未加载时使用 SIM ICCID 尾号写入本地收件箱。

**处理顺序**:
1. `isInNumberBlackList()` → 忽略
2. `isAdmin()` + 命令格式检测 → `processAdminCommand()` → 不再发普通通知
3. `smsStoreAdd()` — 持久化发送方、接收 Profile、设备接收时间与正文
4. `sendSMSToServer()` — 推送所有启用的通道
5. `sendEmailNotification()` — 邮件通知

---

### `void checkSerial1URC()`
**状态机**: `IDLE` ↔ `WAIT_PDU`

IDLE 状态检测 `+CMT:` 行 → 转入 WAIT_PDU。
WAIT_PDU 状态读取 PDU hex 数据 → `pdu.decodePDU()` 解析 → 根据 `concatInfo` 判断长短信/普通短信 → 恢复 IDLE。

---

## 模块: api_handlers.cpp — JSON API

### `void handleApiStatus()`
**用途**: HTTP 端点 `GET /api/status`，返回仪表盘使用的实时设备状态。蜂窝信号来自 SIM 管理器异步缓存，不在 HTTP 请求中同步执行 AT 指令。

**蜂窝信号字段**:

```json
{
  "modem": {
    "rsrp": -93,
    "rsrq": -12.0,
    "signal": {
      "known": true,
      "metric": "RSRP",
      "dbm": -93,
      "raw": 47,
      "rsrq": -12.0,
      "updatedAt": 60089,
      "ageMs": 3043
    }
  }
}
```

`rsrp` 与 `signal.dbm` 的单位为 dBm，`rsrq` 的单位为 dB；`raw` 是
`AT+CESQ` 的 RSRP 原始编码。信号未知、采样超过 45 秒或 SIM 不可用时，数值
字段返回 `null` 且 `known` 为 `false`。

**设备健康字段**:

```json
{
  "health": {
    "state": "healthy",
    "heapTotal": 286156,
    "heapFree": 158704,
    "heapMin": 152132,
    "heapLargest": 114676,
    "heapUsedPercent": 45,
    "fragmentationPercent": 28,
    "partitionLayoutCompatible": true,
    "otaPartitionSize": 1966080,
    "expectedOtaPartitionSize": 1966080,
    "storageReady": true,
    "storageTotal": 131072,
    "storageUsed": 49152,
    "storageUsedPercent": 38,
    "resetReason": "power_on"
  }
}
```

`heapMin` 是本次启动以来的最低可用堆，`heapLargest` 是当前最大连续可分配块。
`state` 由 `health_policy` 根据空闲余量、历史最低值、连续块、碎片率和 LittleFS
状态统一计算，取值为 `healthy`、`warning` 或 `critical`。
`partitionLayoutCompatible` 用备用应用分区的实际容量识别旧分区表。该值为
`false` 时，OTA 只能更新应用，不能创建 LittleFS，必须使用 USB 完整烧录分区表。

## 模块: web_handlers.cpp — HTTP 处理

### 日志系统 API

### `void logCapture(const String& msg)`
### `void logCapture(const char* msg)`
**用途**: 输出日志，但不换行。内容追加到行缓冲区 `_logLine`，不会立即写入环形缓冲区。同时输出到 `Serial`。

**使用场景**: 与 `logCaptureLn()` 配合，构建一行完整日志：
```cpp
logCapture("目标号码: ");
logCaptureLn(String(phoneNumber));
// 环形缓冲区中只有一行: "目标号码: 13800138000"
```

---

### `void logCaptureLn(const String& msg)`
### `void logCaptureLn(const char* msg)`
**用途**: 输出日志并换行。将 `_logLine` + msg 提交到环形缓冲区，然后清空行缓冲区。同时输出到 `Serial.println`。

**注意**: 环形缓冲区每调用一次 `logCaptureLn` 即可产生一行日志，因此 `logCapture()` 和 `logCaptureLn()` 的日志会在环形缓冲区中合并为同一行。每行最多保留 320 字节，超出部分截断，避免异常模组输出持续扩大动态内存。

---

### `void logCaptureF(const char* fmt, ...)`
**用途**: 格式化日志输出（类似 `printf`）。支持 `%d`/`%s`/`%f` 等格式。如果格式化字符串以 `\n` 结尾，自动提交整行到缓冲区。

---

### `void handleLog()`
**用途**: HTTP 端点 `GET /log`，返回环形缓冲区中所有日志行。

**返回格式**: `application/json`
```json
["行1", "行2", "行3", ...]
```
**鉴权**: 需要有效管理会话。最多返回 80 行（环形缓冲区容量）。

---

### `bool checkAuth()`
HTTP Basic Authentication，账号密码来自 `config.webUser` / `config.webPass`。

---

### `void handleRoot()`
返回 SPA 主页 HTML。通过 `html.replace("%KEY%", value)` 替换模板占位符，动态生成 5 个推送通道的表单。页面包含 10 个可切换面板（系统概览/账号管理/邮件通知/推送通道/管理员黑名单/发送短信/模组诊断/网络测试/模组控制/AT终端/系统日志），通过侧边栏 JS 切换显示。

**模板占位符**:

| 占位符 | 数据来源 |
|---|---|
| `%IP%` | `WiFi.localIP().toString()` |
| `%WEB_USER%` / `%WEB_PASS%` | `config.webUser` / `config.webPass` |
| `%SMTP_SERVER%` ~ `%SMTP_SEND_TO%` | `config.smtp*` |
| `%ADMIN_PHONE%` | `config.adminPhone` |
| `%NUMBER_BLACK_LIST%` | `config.numberBlackList` |
| `%SMTP_CHECK%` | 邮件配置是否完整 |
| `%PUSH_COUNT%` | 已启用的有效推送通道数 |
| `%PUSH_CHANNELS%` | 循环生成 5 个通道的 HTML 表单 |

---

### `void handleToolsPage()`
兼容旧链接，直接委托给 `handleRoot()` 返回同一 SPA 页面。

---

### `void handleSave()`
解析 POST 表单 → 写入 `config` → `saveConfig()` → 重新校验 → 发送通知邮件 → 返回成功页面（3 秒跳转）。

---

### `void handleQuery()`
根据 `?type=` 参数执行不同查询：

| type | AT 指令 | 返回内容 |
|---|---|---|
| `ati` | `ATI` | 制造商/型号/固件版本 |
| `signal` | `AT+CESQ` | RSRP/RSRQ 信号强度 |
| `siminfo` | `AT+CIMI` `AT+ICCID` `AT+CNUM` | IMSI/ICCID/本机号码 |
| `network` | `AT+CEREG?` `AT+COPS?` `AT+CGACT?` `AT+CGDCONT?` | 注册/运营商/数据/APN |
| `wifi` | (WiFi 对象) | SSID/RSSI/IP/网关/DNS/MAC/BSSID/信道 |

---

### `void handleFlightMode()`
根据 `?action=` 控制飞行模式：

| action | AT 指令 | 说明 |
|---|---|---|
| `query` | `AT+CFUN?` | 查询当前 CFUN 值 |
| `toggle` | 查询 + `AT+CFUN=1/4` | 1↔4 切换 |
| `on` | `AT+CFUN=4` | 强制开启 |
| `off` | `AT+CFUN=1` | 强制关闭 |

---

### `void handleATCommand()`
通过 `?cmd=` 透传 AT 指令到 `sendATCommand()`，返回 JSON `{success, message}`。

---

### `void handleSendSms()`
解析 POST 表单 phone/content → 调用 `sendSMS()` → 返回 HTML 结果页（3 秒跳转）。

---

### `void handlePing()`
**流程**:
1. `AT+CGACT=1,1` 激活数据连接
2. `AT+MPING="8.8.8.8",30,1` ping 一次（30 秒超时）
3. 解析 `+MPING:` URC 响应，提取 IP/延迟/TTL
4. `AT+CGACT=0,1` 关闭数据连接
5. 返回 JSON `{success, message}`

**注意**: 整个操作最长约 35 秒。

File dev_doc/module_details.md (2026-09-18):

# 模块详解 — 逐文件源码指南

---

## code.ino — 主入口

**文件**: `code/code.ino` (约 105 行)
**角色**: Arduino 工程入口点，仅包含 `setup()` 和 `loop()`。

### setup() 初始化顺序

```
1. GPIO 初始化
   ├── pinMode(LED_BUILTIN, OUTPUT); digitalWrite(HIGH)   // LED 灭
   └── (MODEM_EN_PIN 在 modemPowerCycle 内设置)

2. 串口初始化
   ├── Serial.begin(115200); delay(1500)                   // USB CDC 稳定
   └── Serial1.begin(115200, SERIAL_8N1, RXD, TXD)        // 模组 UART

3. 模组上电
   ├── Serial1.read() 清噪声
   ├── modemPowerCycle()                                     // EN 引脚时序
   └── Serial1.read() 清启动噪声

4. 数据加载
   ├── initConcatBuffer()                                    // 长短信缓存清零
   ├── loadConfig()                                          // NVS → config
   └── configValid = isConfigValid()                        // 校验

5. 模组初始化 (AT 指令序列，每步失败重试+LED闪烁)
   ├── sendATandWaitOK("AT", 1000)                          // 握手
   ├── sendATandWaitOK("AT+CGACT=0,1", 5000)               // 禁数据(省流量)
   ├── sendATCommand("AT+ICCID", 2000)                      // 仅缓存接收卡尾号
   ├── sendATandWaitOK("AT+CNMI=2,2,0,0,0", 1000)          // 短信URC上报
   ├── sendATandWaitOK("AT+CMGF=0", 1000)                   // PDU模式
   └── waitCEREG()                                           // 等网络注册

6. WiFi 连接
   ├── WiFi.setScanMethod(WIFI_ALL_CHANNEL_SCAN)             // 扫描全部信道
   └── WiFi.begin(SSID, PASS, 0, nullptr, true)              // 支持隐藏SSID

7. NTP 时间同步
   ├── configTime(0, 0, "ntp.ntsc.ac.cn", ...)              // UTC时区
   └── 等待 time() > 100000 (最多10秒)

8. HTTP 服务器
   ├── server.on("/", handleRoot)
   ├── server.on("/save", HTTP_POST, handleSave)
   ├── server.on("/tools", handleRoot)                       # 兼容旧链接
   ├── server.on("/sms", handleRoot)                         # 兼容旧链接
   ├── server.on("/sendsms", HTTP_POST, handleSendSms)
   ├── server.on("/ping", HTTP_POST, handlePing)
   ├── server.on("/query", handleQuery)
   ├── server.on("/flight", handleFlightMode)
   ├── server.on("/at", handleATCommand)
   ├── server.on("/log", handleLog)                          # 系统日志 JSON
   └── server.begin()

9. 启动通知
   └── if(configValid) sendEmailNotification("短信转发器已启动", ...)
```

### loop() 执行顺序（每帧执行）

```cpp
server.handleClient();        // 1. 处理HTTP请求
if(!configValid) { ... }      // 2. 配置无效时每秒打印IP
checkConcatTimeout();          // 3. 长短信超时合并转发
if(Serial.available())        // 4. USB->模组透传(单字节)
    Serial1.write(Serial.read());
checkSerial1URC();             // 5. 检查模组URC(短信上报)
```

### 修改指南

- **新增 HTTP 路由**: 在 `web_handlers.h/.cpp` 添加处理函数，然后在 `setup()` 中 `server.on("/path", handler)`
- **调整初始化顺序**: 直接修改 `setup()` 中的代码顺序即可，注意模组初始化必须在 WiFi 之前
- **禁用某功能**: 注释掉对应的 `server.on()` 行即可

---

## config_types.h — 类型定义

**依赖**: 仅 `<Arduino.h>`
**被依赖**: 所有其他模块

### PushType 枚举 (0-10)

表示推送目标平台。值 0 为"未启用"，1-10 对应 10 种推送方式。

**添加新推送类型**:
1. 在 `PushType` 枚举末尾添加新值（如 `PUSH_TYPE_NEW = 11`）
2. 在 `isPushChannelValid()` 添加对应的必填字段校验
3. 在 `sendToChannel()` 添加 `case PUSH_TYPE_NEW:` 实现
4. 在 `handleRoot()` 的 HTML 生成中添加 option
5. 在 HTML JavaScript `updateTypeHint()` 中添加类型提示

### PushChannel 结构体

通用推送通道配置。字段含义:
- `enabled` — 开关
- `type` — PushType 枚举值
- `name` — WebUI 中显示的名称
- `url` — Webhook URL（GET 类型则为目标 URL）
- `key1` — 通用参数 1（token/secret/chat_id 等）
- `key2` — 通用参数 2（channel/bot_token 等）
- `customBody` — 自定义模板的 HTTP body

### Config 结构体

所有可持久化配置的容器，通过 `saveConfig()/loadConfig()` 与 NVS 同步。

### 常量

| 常量 | 值 | 说明 |
|---|---|---|
| `MAX_PUSH_CHANNELS` | 5 | 推送通道数量上限 |
| `MAX_CONCAT_PARTS` | 10 | 长短信最大分段数 |
| `CONCAT_TIMEOUT_MS` | 30000 | 长短信等待超时(ms) |
| `MAX_CONCAT_MESSAGES` | 5 | 同时缓存的长短信组数 |
| `DEFAULT_WEB_USER` | `"admin"` | 默认 Web 账号 |
| `DEFAULT_WEB_PASS` | `"admin123"` | 默认 Web 密码 |

---

## globals.h / globals.cpp — 全局变量

### 全局变量清单

| 变量 | 类型 | 初始化 | 用途 |
|---|---|---|---|
| `config` | `Config` | 默认构造 | 系统全部配置（运行时+持久化） |
| `preferences` | `Preferences` | 默认构造 | NVS 存储接口 |
| `pdu` | `PDU` | `PDU(4096)` | PDU 编解码器（4KB 缓冲区） |
| `ssl_client` | `WiFiClientSecure` | 默认构造 | TLS 客户端（SMTP/HTTPS） |
| `smtp` | `SMTPClient` | `SMTPClient(ssl_client)` | SMTP 邮件客户端 |
| `server` | `WebServer` | `WebServer(80)` | HTTP 服务器（端口 80） |
| `configValid` | `bool` | `false` | 配置是否有效标志 |
| `timeSynced` | `bool` | `false` | NTP 是否已同步 |
| `lastPrintTime` | `unsigned long` | `0` | 上次打印 IP 的 millis |
| `concatBuffer` | `ConcatSms[5]` | 默认构造 | 长短信合并缓存 |

### 功能说明

- **添加新的全局变量**: 在 `globals.h` 添加 `extern` 声明，在 `globals.cpp` 添加定义
- **添加新的库依赖**: 在 `globals.h` 添加 `#include`，所有模块自动获得该依赖

---

## config.h / config.cpp — 配置管理

### NVS 存储结构

```
Namespace: "sms_config"
├── smtpServer  (String)
├── smtpPort    (Int, 默认 465)
├── smtpUser    (String)
├── smtpPass    (String)
├── smtpSendTo  (String)
├── adminPhone  (String)
├── webUser     (String, 默认 "admin")
├── webPass     (String, 默认 "admin123")
├── numBlkList  (String, 换行分隔)
├── push0en     (Bool)
├── push0type   (UChar)
├── push0url    (String)
├── push0name   (String)
├── push0k1     (String)
├── push0k2     (String)
├── push0body   (String)
├── push1en ... (同上 × 4)
└── ...
```

### 兼容迁移机制

`loadConfig()` 末尾检查旧 key `httpUrl` 和 `barkMode`，若存在则自动迁移到 `pushChannels[0]`。这是旧版单通道配置 → 新版多通道配置的迁移路径。

### 修改指南

- **添加新配置项**: 在 `Config` 结构体加字段 → `loadConfig()` 加读取（设默认值） → `saveConfig()` 加写入 → `handleSave()` 加表单解析
- **修改校验逻辑**: 编辑 `isPushChannelValid()` 和 `isConfigValid()`

---

## modem.h / modem.cpp — 模组控制

### 串口通信模型

```
ESP32-C3                   4G 模组
  Serial1 (UART) ──────────── AT 端口
  GPIO 5     ──────────── EN 引脚
```

### AT 指令函数对比

| 函数 | 返回类型 | 延时处理 | 适用场景 |
|---|---|---|---|
| `sendATCommand()` | String (完整响应) | 收到 OK/ERROR 后 `delay(50)` | 需要解析响应内容 |
| `sendATandWaitOK()` | bool | 无额外 delay | 快速幂等检查 |

### 模组电源控制

```
modemPowerCycle():
  EN=HIGH (默认)  模组运行
      ↓
  EN=LOW (1200ms) 模组断电
      ↓
  EN=HIGH (6000ms) 模组上电启动
```

6000ms 是关键时间，太短模组初始化未完成会导致 AT 无响应。

### sendSMS() 时序图

```
ESP32                         模组
  │                            │
  ├─ AT+CMGS=<len>\r\n ──────►│
  │                            │
  │◄───────────────────── >  │  (提示符)
  │                            │
  ├─ PDU hex data + 0x1A ────►│
  │                            │
  │◄──────────────── +CMGS:   │  (成功响应)
  │◄──────────────── OK       │
```

### 修改指南

- **更换模组型号**: 修改 `modemPowerCycle()` 的时序参数，调整 AT 指令序列
- **添加新 AT 功能**: 实现新函数，使用 `sendATCommand()` 或直接操作 `Serial1`
- **调波特率**: 修改 `Serial1.begin()` 参数 + 模组 AT 配置

---

## push.h / push.cpp — 推送服务

### 推送通道执行流程

```
sendSMSToServer(sender, message, timestamp)
  │
  ├─ 检查 WiFi 连接
  ├─ 检查是否有启用的有效通道
  │
  └─ for each valid channel:
       └─ sendToChannel(channel, sender, message, timestamp)
            │
            ├─ jsonEscape() 转义 sender/message/timestamp
            │
            └─ switch(channel.type):
                 ├─ POST_JSON  → POST {sender, message, timestamp}
                 ├─ BARK       → POST {title, body}
                 ├─ GET        → GET ?sender=&message=&timestamp=
                 ├─ DINGTALK   → POST {msgtype:"text", text:{content:"..."}}
                 │               ├─ 有secret → dingtalkSign() 追加URL参数
                 ├─ PUSHPLUS   → POST {token, title, content, channel}
                 │               └─ 默认URL: http://www.pushplus.plus/send
                 ├─ SERVERCHAN → POST title=&desp= (form-urlencoded)
                 │               └─ 默认URL: https://sctapi.ftqq.com/{key1}.send
                 ├─ CUSTOM     → POST (使用 customBody 模板替换)
                 ├─ FEISHU     → POST {timestamp?, sign?, msg_type, content}
                 │               └─ 有secret → HMAC-SHA256签名
                 ├─ GOTIFY     → POST {title, message, priority}
                 │               └─ URL: {url}/message?token={key1}
                 └─ TELEGRAM   → POST {chat_id, text}
                     └─ 默认URL: https://api.telegram.org/bot{key2}/sendMessage
```

### HMAC 签名实现

钉钉和飞书都使用 `mbedtls_md` 库（ESP32 内置）:
```cpp
mbedtls_md_context_t ctx;
mbedtls_md_init(&ctx);
mbedtls_md_setup(&ctx, MBEDTLS_MD_SHA256, 1);
mbedtls_md_hmac_starts(&ctx, key, keyLen);
mbedtls_md_hmac_update(&ctx, data, dataLen);
mbedtls_md_hmac_finish(&ctx, hmacResult);
mbedtls_md_free(&ctx);
// hmacResult → base64::encode() → urlEncode()
```

### 邮件发送

使用 ReadyMail 库的 SMTP 客户端:
```cpp
smtp.connect(server, port, callback);
smtp.authenticate(user, pass, readymail_auth_password);
SMTPMessage msg;
msg.headers.add(rfc822_from, from);
msg.headers.add(rfc822_to, to);
msg.headers.add(rfc822_subject, subject);
msg.text.body(body);
msg.timestamp = time(nullptr);
smtp.send(msg);
```

### 修改指南

- **添加新推送通道**: 在 `PushType` 加枚举 → `isPushChannelValid()` 加校验 → `sendToChannel()` 加 case → Web UI 加选项
- **修改钉钉/飞书签名逻辑**: 编辑 `dingtalkSign()` 或 `sendToChannel()` 中 FEISHU case
- **更换 SMTP 库**: 只需修改 `sendEmailNotification()` 函数

---

## sms_process.h / sms_process.cpp — 短信处理

### 长短信合并状态机

```
┌─────────────────────────────────────────────────────┐
│                  concatBuffer[0..4]                  │
│  ┌─────────┐  ┌─────────┐      ┌─────────┐         │
│  │ Slot 0  │  │ Slot 1  │ ...  │ Slot 4  │         │
│  │ inUse   │  │ inUse   │      │ inUse   │         │
│  │ refNum  │  │ refNum  │      │ refNum  │         │
│  │ total   │  │ total   │      │ total   │         │
│  │ recv'd  │  │ recv'd  │      │ recv'd  │         │
│  │ time    │  │ time    │      │ time    │         │
│  │ parts[] │  │ parts[] │      │ parts[] │         │
│  └─────────┘  └─────────┘      └─────────┘         │
└─────────────────────────────────────────────────────┘
```

### PDU 解析流程

```
checkSerial1URC() 循环:
  ┌─ IDLE 状态 ──────────────────────────────────────┐
  │  逐行读取 Serial1                                 │
  │  检测 "+CMT:" → 转入 WAIT_PDU                    │
  └──────────────────────────────────────────────────┘
                       │
  ┌─ WAIT_PDU 状态 ──────────────────────────────────┐
  │  读取下一行                                       │
  │  isHexString()?                                   │
  │    ├─ 是 → pdu.decodePDU(line)                   │
  │    │       ├─ 失败 → 打印错误, 回 IDLE            │
  │    │       └─ 成功 → 提取 sender/text/timestamp   │
  │    │                → 检查 concatInfo              │
  │    │                  ├─ 长短信 → 缓存分段         │
  │    │                  │   └─ 收齐? → 合并→process │
  │    │                  └─ 普通短信 → process        │
  │    └─ 否 → 回 IDLE                               │
  └──────────────────────────────────────────────────┘
```

### 黑名单匹配算法

```
原始发送者号码: "+8613800138000"
  │
  ├─ 提取纯号码: "13800138000" (去+86)
  │
  └─ 逐行对比黑名单:
       黑名单行 "13800138000" → 匹配 ✓
       黑名单行 "13900139000" → 不匹配
       黑名单行 "+8613800138000" → 匹配 ✓ (用原始号码对比)
```

### 管理员命令解析

```
短信内容: "SMS:13800138000:你好世界"
  │
  ├─ 第一个 ':'  → "SMS"
  ├─ 第二个 ':'  → "13800138000"  (目标号码)
  └─ 剩余内容    → "你好世界"      (短信内容)
  │
  └─ sendSMS("13800138000", "你好世界")

短信内容: "RESET"
  └─ resetModule() + ESP.restart()
```

### 修改指南

- **调整长短信超时**: 修改 `CONCAT_TIMEOUT_MS` 宏（config_types.h）
- **修改黑名单匹配逻辑**: 编辑 `isInNumberBlackList()`
- **添加新管理员命令**: 在 `processAdminCommand()` 中添加 `else if` 分支
- **更换短信库**: 修改 `checkSerial1URC()` 中的 `pdu.decodePDU()` 调用

---

## web_handlers.h / web_handlers.cpp — HTTP 处理 + 日志系统

### 路由表

| 方法 | 路径 | 处理函数 | Auth | 说明 |
|---|---|---|---|---|
| GET | `/` | `handleRoot()` | ✓ | SPA 主页（含 10 个面板） |
| GET | `/tools` | `handleRoot()` | ✓ | 旧链接兼容，返回同一 SPA 页面 |
| GET | `/sms` | `handleRoot()` | ✓ | 旧链接兼容，返回同一 SPA 页面 |
| POST | `/save` | `handleSave()` | ✓ | 保存配置 |
| POST | `/sendsms` | `handleSendSms()` | ✓ | 网页发送短信 |
| POST | `/ping` | `handlePing()` | ✓ | Ping 测试 |
| GET | `/query` | `handleQuery()` | ✓ | 模组/WiFi 信息查询 |
| GET | `/flight` | `handleFlightMode()` | ✓ | 飞行模式控制 |
| GET | `/at` | `handleATCommand()` | ✓ | AT 指令调试 |
| GET | `/log` | `handleLog()` | ✓ | 系统日志（JSON 数组） |

### 日志环形缓冲区

```
容量: LOG_BUF_SIZE = 80 行，每行最多 320 字节
结构: String logBuffer[80] + 有界行缓冲 _logLine
写入:
  logCapture(msg)      → Serial.print() + 追加到 _logLine
  logCaptureLn(msg)    → Serial.println() + 提交 _logLine 到环形缓冲区
  logCaptureF(fmt,...) → Serial.print() + 追加到 _logLine (fmt 以 \n 结尾时自动提交)
读取:
  handlerLog()         → JSON ["行1","行2",...] (按插入顺序)
```

**行缓冲设计目的**: 避免 `logCapture("A:"); logCaptureLn(B);` 在环形缓冲区中产生两个独立条目。实际只产生一行 `"A: B"`。长度上限用于阻止连续异常输出造成动态内存持续增长。

### 模板变量替换

SPA 页面中的 `%PLACEHOLDER%` 在 `handleRoot()` 中通过 `html.replace()` 替换:

| 占位符 | 数据来源 |
|---|---|
| `%IP%` | `WiFi.localIP().toString()` |
| `%WEB_USER%` / `%WEB_PASS%` | `config.webUser` / `config.webPass` |
| `%SMTP_SERVER%` ~ `%SMTP_SEND_TO%` | `config.smtp*` |
| `%ADMIN_PHONE%` | `config.adminPhone` |
| `%NUMBER_BLACK_LIST%` | `config.numberBlackList` |
| `%PUSH_CHANNELS%` | 循环生成 5 个通道的 HTML 表单 |

### 响应格式

| 端点 | Content-Type | 返回格式 |
|---|---|---|
| `/` `/tools` `/sms` `/save` | `text/html` | HTML 页面 |
| `/query` `/flight` `/at` `/ping` | `application/json` | `{"success":bool, "message":"..."}` |
| `/log` | `application/json` | `["行1", "行2", ...]` |

### 修改指南

- **添加新页面**: 在 `web_handlers.cpp` 添加处理函数 → `setup()` 注册路由
- **修改页面样式**: 编辑 `web_html.cpp` 中的 HTML 模板
- **添加查询类型**: 在 `handleQuery()` 的 if-else 链中添加新 type

---

## web_html.h / web_html.cpp — HTML 模板

### 内容说明

**单页应用 (SPA)**：整个项目仅一个 HTML 常量 `htmlPage`（约 500 行），包含 10 个面板：

| 面板 ID | 名称 | 功能 |
|---|---|---|
| `panel-overview` | 系统概览 | 显示 IP/信号/配置状态 |
| `panel-account` | 账号管理 | 修改 Web 登录密码 |
| `panel-email` | 邮件通知 | SMTP 邮件配置 |
| `panel-push` | 推送通道 | 5 个推送通道配置 |
| `panel-admin` | 管理员 & 黑名单 | 管理员号码 + 号码黑名单 |
| `panel-sendsms` | 发送短信 | Web 端发送短信 |
| `panel-diagnose` | 模组诊断 | ATI/信号/SIM/网络查询 |
| `panel-network` | 网络测试 | Ping 测试 |
| `panel-modem` | 模组控制 | 飞行模式开关/模组重启 |
| `panel-atterm` | AT 终端 | AT 指令交互调试 |
| `panel-log` | 系统日志 | 实时日志查看（终端风格） |

**侧边栏**分为"配置"和"工具"两个分组，底部有"修改密码"快捷按钮。JS 通过 `switchPanel(name)` 控制面板显示/隐藏，日志面板激活时自动开始轮询，切换离开后停止。

### 修改指南

- 直接编辑 `web_html.cpp` 中的 `R"rawliteral(...)rawliteral"` 块
- HTML 中的 `"` 在 `R"rawliteral"` 中不需要转义
- 需要动态内容的地方使用 `%PLACEHOLDER%`，在对应 handler 中 replace

---

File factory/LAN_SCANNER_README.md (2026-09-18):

# SMS Forwarder 局域网发现工具

双击 `sms-forwarder-lan-scanner.exe` 后，工具会自动广播发现请求，并列出同一局域网内的 SMS Forwarder 设备。双击设备或点击“打开管理页面”即可进入管理台。

工具只读取设备 IP、Wi-Fi MAC、设备 ID、固件版本、蜂窝模组型号和 OTA 能力，不读取手机号、ICCID、短信、Wi-Fi 密码或通知密钥。

## 无法发现设备

1. 确认电脑和设备连接到同一路由器或同一个设备配置热点。
2. 关闭路由器的 AP 隔离、访客网络隔离或无线终端隔离。
3. 如果 Windows 防火墙首次询问，请允许工具访问“专用网络”。
4. 旧固件没有发现协议；请先通过 USB 或 OTA 升级到 v1.6.0 及以上版本。

发现协议使用 UDP 37888，只回应同一 IPv4 子网内、格式和随机 nonce 均有效的请求。

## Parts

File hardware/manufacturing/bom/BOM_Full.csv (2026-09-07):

Comment | Designator | Footprint | LCSC Part # | Quantity | Manufacturer | Manufacturer Part # | Assembly | Notes
ESP32-C3-MINI-1-N4 | U1 | SMD 13.2x16.6 mm | C2838502 | 1 | Espressif | ESP32-C3-MINI-1-N4 | SMT
ML307A-DSLN | U2 | LGA-94 17.7x15.8 mm | C5375091 | 1 | China Mobile IoT | ML307A-DSLN | SMT | Alternative: ML307A-DCLN / C5362285. Do not fit ML307C/Y on this PCB revision.
SY8205FCC | U3 | SOIC-8-EP | C111875 | 1 | Silergy | SY8205FCC | SMT
AP2112K-3.3 | U4 | SOT-23-5 | C51118 | 1 | Diodes Incorporated | AP2112K-3.3TRG1 | SMT
TXU0202 | U5 | VSSOP-8 | C5186957 | 1 | Texas Instruments | TXU0202DCUR | SMT
USBLC6-2SC6 | U6 | SOT-23-6 | C2687116 | 1 | UMW | USBLC6-2SC6 | SMT
SRV05-4 | U7 | SOT-23-6 | C558418 | 1 | TECH PUBLIC | SRV05-4 | SMT
USB-A male | J1 | THT | C404965 | 1 | Korean Hroparts Elec | AM90 | THT/manual
Nano SIM | J2 | SMD 1.45 mm | C53200251 | 1 | XYECONN | NANO SIM 6PIN 1.45H | SMT
U.FL | J3,J4 | SMD | C88373 | 2 | Hirose | U.FL-R-SMT-1(10) | SMT
2 A PTC | F1 | 1206 | C70167 | 1 | TECHFUSE | SL1206200 | SMT
4.7 uH | L1 | 7.0x6.6 mm | C5307631 | 1 | XR | XR0630-4R7M | SMT
220 uF 6.3 V | C5,C6 | D5xL5.3 mm | C2162607 | 2 | Nippon Chemi-Con | APXF6R3ARA221ME61G | SMT
22 uF 10 V | C1,C2 | 0805 | C45783 | 2 | Samsung | CL21A226MPQNNNE | SMT
47 uF 6.3 V | C3,C4 | 0805 | C96123 | 2 | Samsung | CL21A476MQYNNNE | SMT
10 uF 10 V | C11,C12 | 0603 | C19702 | 2 | Samsung | CL10A106KP8NNNC | SMT
100 nF | C8,C13,C14,C16,C17,C18 | 0402 | C1525 | 6 | Samsung | CL05B104KO5NNNC | SMT
10 nF | C9 | 0402 | C15195 | 1 | Samsung | CL05B103KB5NNNC | SMT
1 uF | C10 | 0402 | C52923 | 1 | Samsung | CL05A105KA5NNNC | SMT
1 uF | C15 | 0402 | C52923 | 1 | Samsung | CL05A105KA5NNNC | SMT
22 pF | C7 | 0402 | C1555 | 1 | Samsung | CL05C220JB5NNNC | SMT
33 pF | C19,C20,C21,C22 | 0402 | C1562 | 4 | Samsung | CL05C330JB5NNNC | SMT
DNP | C23,C24,C25,C26 | 0402 |  | 4 | - | DNP | DNP | Select after antenna/VNA validation.
536 k | R1 | 0402 | C72998 | 1 | UNI-ROYAL | 0402WGF5363TCE | SMT
100 k | R2 | 0402 | C25741 | 1 | UNI-ROYAL | 0402WGF1003TCE | SMT
10 k | R3,R4,R6,R13 | 0402 | C25744 | 4 | UNI-ROYAL | 0402WGF1002TCE | SMT
4.7 k | R7 | 0402 | C25900 | 1 | UNI-ROYAL | 0402WGF4701TCE | SMT
100 k | R8,R18 | 0402 | C25741 | 2 | UNI-ROYAL | 0402WGF1003TCE | SMT
22 R | R9,R10,R11,R12,R16,R17 | 0402 | C25092 | 6 | UNI-ROYAL | 0402WGF220JTCE | SMT
0 R | R14,R15 | 0402 | C17168 | 2 | UNI-ROYAL | 0402WGF0000TCE | SMT
1 k | R5 | 0402 | C11702 | 1 | UNI-ROYAL | 0402WGF1001TCE | SMT
SMF5.0A | D1 | SOD-123FL | C1509112 | 1 | JSCJ | SMF5.0A | SMT
Green LED | D2 | 0603 | C965804 | 1 | XINGLIGHT | XL-1608UGC-04 | SMT
Tact switch | SW1,SW2 | 3.0x2.5 mm SMD | C72443 | 2 | C&K | KMR221GLFS | SMT
Test pad | TP1,TP2,TP3,TP4,TP5,TP6 | 1.0 mm pad |  | 6 | - | PCB pad | PCB

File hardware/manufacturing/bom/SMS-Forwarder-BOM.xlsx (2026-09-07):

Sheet: BOM
SMS Forwarder Board — Rev 1.0 BOM |  |  |  |  |  |  |  |  | Build summary | Value
ESP32-C3-MINI-1 + ML307A 94-pin engineering sample. Quantities are per assembled PCB. |  |  |  |  |  |  |  |  | Planned PCB qty | 5
 |  |  |  |  |  |  |  |  | SMT parts / PCB | 56
Value | Designators | Package | LCSC Part # | Qty / PCB | Manufacturer | Manufacturer Part # | Assembly | Notes | SMT placements | 280
ESP32-C3-MINI-1-N4 | U1 | SMD 13.2x16.6 mm | C2838502 | 1 | Espressif | ESP32-C3-MINI-1-N4 | SMT |  | Manual / DNP lines | 3
ML307A-DSLN | U2 | LGA-94 17.7x15.8 mm | C5375091 | 1 | China Mobile IoT | ML307A-DSLN | SMT | Alternative: ML307A-DCLN / C5362285. Do not fit ML307C/Y on this PCB revision. | PCB size | 40 × 84 mm
SY8205FCC | U3 | SOIC-8-EP | C111875 | 1 | Silergy | SY8205FCC | SMT
AP2112K-3.3 | U4 | SOT-23-5 | C51118 | 1 | Diodes Incorporated | AP2112K-3.3TRG1 | SMT
TXU0202 | U5 | VSSOP-8 | C5186957 | 1 | Texas Instruments | TXU0202DCUR | SMT
USBLC6-2SC6 | U6 | SOT-23-6 | C2687116 | 1 | UMW | USBLC6-2SC6 | SMT
SRV05-4 | U7 | SOT-23-6 | C558418 | 1 | TECH PUBLIC | SRV05-4 | SMT
USB-A male | J1 | THT | C404965 | 1 | Korean Hroparts Elec | AM90 | THT/manual
Nano SIM | J2 | SMD 1.45 mm | C53200251 | 1 | XYECONN | NANO SIM 6PIN 1.45H | SMT
U.FL | J3,J4 | SMD | C88373 | 2 | Hirose | U.FL-R-SMT-1(10) | SMT
2 A PTC | F1 | 1206 | C70167 | 1 | TECHFUSE | SL1206200 | SMT
4.7 uH | L1 | 7.0x6.6 mm | C5307631 | 1 | XR | XR0630-4R7M | SMT
220 uF 6.3 V | C5,C6 | D5xL5.3 mm | C2162607 | 2 | Nippon Chemi-Con | APXF6R3ARA221ME61G | SMT
22 uF 10 V | C1,C2 | 0805 | C45783 | 2 | Samsung | CL21A226MPQNNNE | SMT
47 uF 6.3 V | C3,C4 | 0805 | C96123 | 2 | Samsung | CL21A476MQYNNNE | SMT
10 uF 10 V | C11,C12 | 0603 | C19702 | 2 | Samsung | CL10A106KP8NNNC | SMT
100 nF | C8,C13,C14,C16,C17,C18 | 0402 | C1525 | 6 | Samsung | CL05B104KO5NNNC | SMT
10 nF | C9 | 0402 | C15195 | 1 | Samsung | CL05B103KB5NNNC | SMT
1 uF | C10 | 0402 | C52923 | 1 | Samsung | CL05A105KA5NNNC | SMT
1 uF | C15 | 0402 | C52923 | 1 | Samsung | CL05A105KA5NNNC | SMT
22 pF | C7 | 0402 | C1555 | 1 | Samsung | CL05C220JB5NNNC | SMT
33 pF | C19,C20,C21,C22 | 0402 | C1562 | 4 | Samsung | CL05C330JB5NNNC | SMT
DNP | C23,C24,C25,C26 | 0402 |  | 4 | - | DNP | DNP | Select after antenna/VNA validation.
536 k | R1 | 0402 | C72998 | 1 | UNI-ROYAL | 0402WGF5363TCE | SMT
100 k | R2 | 0402 | C25741 | 1 | UNI-ROYAL | 0402WGF1003TCE | SMT
10 k | R3,R4,R6,R13 | 0402 | C25744 | 4 | UNI-ROYAL | 0402WGF1002TCE | SMT
4.7 k | R7 | 0402 | C25900 | 1 | UNI-ROYAL | 0402WGF4701TCE | SMT
100 k | R8,R18 | 0402 | C25741 | 2 | UNI-ROYAL | 0402WGF1003TCE | SMT
22 R | R9,R10,R11,R12,R16,R17 | 0402 | C25092 | 6 | UNI-ROYAL | 0402WGF220JTCE | SMT
0 R | R14,R15 | 0402 | C17168 | 2 | UNI-ROYAL | 0402WGF0000TCE | SMT
1 k | R5 | 0402 | C11702 | 1 | UNI-ROYAL | 0402WGF1001TCE | SMT
SMF5.0A | D1 | SOD-123FL | C1509112 | 1 | JSCJ | SMF5.0A | SMT
Green LED | D2 | 0603 | C965804 | 1 | XINGLIGHT | XL-1608UGC-04 | SMT
Tact switch | SW1,SW2 | 3.0x2.5 mm SMD | C72443 | 2 | C&K | KMR221GLFS | SMT
Test pad | TP1,TP2,TP3,TP4,TP5,TP6 | 1.0 mm pad |  | 6 | - | PCB pad | PCB

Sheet: Build Notes
Build notes and first-article controls
PCB parameter | Required value |  | Modem option | PCB fit | Action
PCB outline | 40 × 84 mm |  | ML307A-DSLN | Supported | Default BOM: C5375091
Layer count | 4 |  | ML307A-DCLN | Supported | Alternative: C5362285; confirm GNSS requirement
Thickness | 1.6 mm |  | ML307C | Not compatible | Requires a separate 109-pin PCB
Copper | Outer 1 oz; inner 0.5 oz |  | ML307Y | Not compatible | Requires a separate 109-pin PCB
Recommended stackup | JLC04161H-7628
Surface finish | ENIG 1U" or lead-free HASL
Input power | Regulated 5 V / 2 A minimum
Assembly plan | Order 5 bare PCBs; assemble 2 first articles
First-article sequence
1 | Assemble USB input, 3.3 V rail and ESP32-C3 only | Limit input to 300 mA; confirm USB enumeration and 3.20–3.40 V
2 | Assemble the 3.8 V buck without ML307A | Load-step 0.1 A → 1 A → 2 A; rail must stay above 3.4 V
3 | Assemble ML307A, level translator, SIM and RF path | Attach a 50 Ω LTE antenna before modem power-up
4 | Check UART and SIM | 100 × AT/ATI; CPIN READY; ICCID readable
5 | Check network and SMS | Record PLMN/band/RSRP; 20 uplink and 20 downlink SMS
6 | Run stability test | 24 h Wi-Fi + LTE + SMS workload without reset or memory loss
7 | Release volume assembly | Only after electrical, RF and thermal results are signed off
Design sources
ESP32-C3 hardware design guidelines | https://documentation.espressif.com/esp-hardware-design-guidelines/en/latest/esp32c3/index.html
ESP32-C3-MINI-1 datasheet | https://documentation.espressif.com/esp32-c3-mini-1_datasheet_en.html
JLCPCB impedance stackups | https://jlcpcb.com/impedance
ML307A Hardware Design Manual | Obtain the current controlled copy from the module supplier

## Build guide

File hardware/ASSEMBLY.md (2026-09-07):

# 装配与首板验证

## 贴装顺序

1. 首先不贴 U2/ML307，仅贴 USB 输入、3.3 V LDO、ESP32-C3 及其外围。
2. 限流电源设为 5.0 V/300 mA，确认 `+3V3` 为 3.20–3.40 V，ESP32-C3 USB 能枚举并可烧录。
3. 贴装 SY8205、L1 和 3.8 V 电源外围，继续不贴 U2。GPIO5 拉高后确认 `+3V8_MODEM` 为 3.74–3.89 V；用电子负载从 0.1 A 增加到 2.0 A，检查温升、纹波和瞬态跌落。测试台电源与连接线必须能稳定提供 5 V/2 A。
4. 电源测试通过后贴 ML307A、TXU0202、SIM 与天线网络。LTE MAIN 的串联位 R14 装 0 Ω，C23/C24 暂不贴；GNSS 同理。
5. 首板不要依赖板载天线测试 LTE，J3 必须连接 50 Ω LTE 天线后再开机。

## 必测项目

| 项目 | 测试方法 | 合格条件 |
| --- | --- | --- |
| USB 输入 | 5 V/2 A 电源，测 F1 两端 | 稳态压降小于 120 mV |
| 3.3 V | ESP32-C3 Wi-Fi 连续发包 | 3.20–3.40 V，无复位 |
| 3.8 V | 电子负载 0.1/1/2 A 阶跃 | 不低于 3.4 V；稳态 3.74–3.89 V |
| 硬断电 | 在网页执行模组重启 | GPIO5 低时 U2 VBAT 接近 0 V，高后自动启动 |
| UART | 115200 8N1 执行 `AT`/`ATI` | 连续 100 次无乱码、无超时 |
| SIM | 插卡后执行 `AT+CPIN?`/`AT+ICCID` | READY 且 ICCID 可读 |
| 驻网 | 三家运营商分别测试 | 支持频段与 SIM 策略允许时可注册；记录 PLMN/频段/RSRP |
| 短信 | 上下行各 20 条，含中文长短信 | 无丢失、无重复、转发内容正确 |
| 射频 | 暗室或传导测试 | 按当地法规与运营商认证要求执行 |
| 稳定性 | 24 小时 Wi-Fi + LTE + 短信压力测试 | 无看门狗重启、无模组掉电、无内存持续下降 |

## 量产注意事项

- ML307A 的 UART 为 1.8 V，禁止用 3.3 V USB-TTL 直接连接模组 UART0。
- 模组贴装后不能用热风长时间集中加热底部 LGA；首件应做 X-Ray 或切片抽检。
- U.FL 插拔寿命有限，产测夹具优先使用同轴测试头，不要反复手工拔插。
- `ML307A-DSLN` 和 `ML307A-DCLN` 使用相同 94-pin PCB 版本；是否具有 GNSS 以采购料号和供应商规格为准。
- RF π 网络的 DNP 电容值只能在成品外壳、天线和线缆确定后通过 VNA/射频测试选择。
- Rev 1.0 的 0.38 mm RF 线宽与 0.20/0.20 mm USB 差分名义值必须在下单时按实际 JLC04161H-7628 叠层重新核算，采用工厂给出的阻抗补偿值。
- 首件贴装前在 JLC 的 BOM/CPL 预览中逐项核对极性、Pin 1 与底层器件镜像方向，不应只依赖自动匹配结果。

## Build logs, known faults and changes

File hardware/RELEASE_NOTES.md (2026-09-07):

# Hardware Rev 1.0.0

Rev 1.0.0 is the first published engineering-sample hardware design for the SMS Forwarder Board.

## Included

- Editable KiCad 10 schematic, PCB and project libraries.
- 40 × 84 mm, four-layer ESP32-C3-MINI-1 + ML307A board.
- USB-A power/native USB, Nano SIM, UART level translation and modem power switching.
- External LTE MAIN and optional GNSS U.FL connectors with RF matching footprints.
- JLCPCB Gerber, Excellon drill, SMT BOM and dual-side placement data.
- Full BOM workbook, schematic PDF, PCB layout PDF and top/bottom renders.

## Verification state

- KiCad 10.0.6 ERC: 0 errors, 0 warnings.
- KiCad 10.0.6 DRC: 0 violations, 0 unconnected pads, 0 footprint errors.
- BOM/CPL reconciliation: 56 SMT placements in both files.
- Physical first-article validation: pending.

Order five bare PCBs and assemble two first articles before volume production. Follow `ASSEMBLY.md` for staged power, RF, SIM, SMS and 24-hour stability checks.

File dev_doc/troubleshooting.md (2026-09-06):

# 现场排障记录

本文只记录已经在真实设备上复现并闭环的故障。示例不包含 IMSI、完整 ICCID、短信正文或验证码。

## 3HK × 46011 × ML307R-DC：网络已注册但收不到短信（2026-07-12）

### 现象

- 3 Hong Kong Profile 插在 ML307R-DC 时，网页显示 SIM、信号和 LTE 漫游注册均正常，但新短信不到达。
- 把同一张卡/Profile 放回手机后，手机会把模块期间未交付的短信集中收到。
- APN、网页刷新和 PDU 解码设置都无法改变现象。

### 现场证据

故障网络为自动选择的中国电信 `46011`，模块现场状态如下：

```text
ATI         -> ML307R-DC
AT+CPIN?    -> READY
AT+CEREG?   -> stat=5（EPS 漫游注册）
AT+COPS?    -> 46011 / LTE
AT+CSQ      -> 22,99
AT+CGATT?   -> 1
AT+CNMI?    -> 2,2,0,0,0
AT+CMGF?    -> 0（PDU）
AT+CPMS?    -> ME 0/180；SM 0/5
```

失败期间没有出现 `+CMT` 或 `+CMTI`，ME/SM 也都为空。因此短信没有到达模块存储或 UART，网页、ESP32 和 PDU 解析器尚未参与，不能把问题归因于前端漏显示。

手机 Root 日志确认，积压短信在插回手机后作为新的网络下行短信事件到达，而不是从 SIM 存储导入。这说明短信中心此前没有完成对 ML307R-DC 的投递确认，并在手机重新建立可用短信服务后重投。

### 处理结果

在“SIM / eSIM → 运营商选网”中手动选择中国联通 `46001` 后：

- `AT+COPS?` 确认当前 PLMN 为 `46001`、LTE；
- 管理台显示中国联通，选择模式为“手动 / 自动回退”；
- 新短信接收立即恢复。

本次结论限定为 **3HK Profile × 46011 访问网 × ML307R-DC 的 MT SMS 承载兼容性问题**，不能泛化为所有中国电信卡或网络都不支持短信。

### 原理与容易误判的点

1. `CEREG=1/5` 只说明 EPS 本地/漫游注册成功，不代表网络已经接受 non-EPS 或 SMS-only 服务。网络可以允许 LTE 数据注册，同时不提供该终端所需的短信承载。
2. OneMO 官方手册明确说明 ML307R-DC 不支持 IMS 短信，因此它依赖访问网提供兼容的非 IMS LTE 短信路径。参见 [ML307R 通信流程示例 V1.0.1，第 16 页](https://m5stack-doc.oss-cn-shenzhen.aliyuncs.com/1189/ML307R_Communication_Process_Example_V1.0.1.pdf)。
3. APN/PDP 主要服务数据连接，修改普通 APN 不会给模块增加缺失的 IMS 或 EPS-NAS 短信能力。
4. `CNMI`、`CMGF` 成功只证明本地短信接口已经配置，不能证明网络可以把 MT SMS 交付到模块。

### 快速分层方法

在失败短信发出后、拔卡前依次检查：

```text
AT+CPIN?
AT+COPS?
AT+CEREG?
AT+CNMI?
AT+CMGF?
AT+CPMS?
```

- 有 `+CMT/+CMTI`，或 CPMS/CMGL 能看到短信：继续检查 ESP32 串口消费、PDU 解码和启动补扫。
- 没有 URC 且 ME/SM 均为空，随后手机能收到积压短信：优先检查访问 PLMN、漫游协议与模块短信承载兼容性。
- 切换到另一个允许注册的 PLMN 后立即恢复：可闭环为访问网/模块承载组合问题，不再围绕 APN 或网页反复排查。

### 防复发

- 手动选网使用 `AT+COPS=4`。目标网失败时会自动回退到自动选网，需重新核对当前 PLMN，不能只看任务曾经显示“完成”。
- eSIM Profile 切换流程会恢复 `AT+COPS=0`，切换后必须重新核对访问网；必要时再次选择已经验证可收短信的 PLMN。
- 管理台中的“短信接口已配置”和“短信端到端可达”应分开理解。当前固件无法仅凭 `CEREG` 主动证明短信可达，最终仍需发送一条探针短信验证。

## ML307Y 选网后短信上报被关闭（2026-09-06）

### 现象与复现

ML307Y 在扫描并执行 `AT+COPS=4` 选网后仍能驻留 LTE，`CPIN/CREG/CEREG` 也正常，但新短信不再进入 ESP32。现场复现到选网前后配置发生如下变化：

```text
选网前 AT+CNMI? -> 2,2,0,0,0
选网后 AT+CNMI? -> 0,0,0,0,0
选网后 AT+CMGF? -> 0
```

`CNMI` 被清零后不会产生 `+CMT` 或 `+CMTI`，所以网页、PDU 解码和本地收件箱都看不到任何事件。

### 修复

运营商扫描、手动选择和恢复自动选网无论成功或失败，任务释放模组后都会请求 SIM 管理器重新执行短信配置链。该流程恢复 PDU 模式和 `AT+CNMI=2,2,0,0,0`，并在恢复期间暂停主动发送，避免选网操作造成持久的静默漏收。

恢复配置后还会扫描 SIM 的短信槽位。现场发现 8 条积压短信时，固件将 8 条全部解析并写入 LittleFS，再逐条执行 `CMGD`；处理结束后 `CPMS` 从 `8/50` 降为 `0/50`。随后完成了一次自发自收验证，收件箱实时增加 1 条，证明发送、网络回送、PDU 解析、本地存储和企业微信推送链路均已恢复。

## 短信时间显示为 2796 年

### 根因

`pdulib 0.5.11` 的 `getTimeStamp()` 返回 GSM SCTS，而不是 Unix 时间。同版本实现实际输出 7 个 SCTS 字节：`YYMMDDHHMMSS` 加两位时区；旧前端把这串纯数字按 Unix 毫秒解析，因此出现 2796 年等错误日期。[对应源码](https://github.com/mgaman/PDUlib/blob/dbf324a13f79cfcba8d408afee9e1246adb9d762/src/pdulib.cpp#L683-L692)

### 修复约定

- 旧记录继续保留原始 SCTS，网页按年月日时分秒和 15 分钟单位的时区正确解析，并标为“短信中心时间（历史记录）”。
- 新记录在收到首个 PDU 分段时保存 NTP 校准后的 UTC ISO-8601 时间，并标为“设备接收时间”；企业微信等人可读通知会转换成明确标注的北京时间。
- NTP 尚未有效时不保存 1970 年，而是回退到可解析的 SCTS。
- 持久化结构和版本保持不变，升级不会清空现有短信。

## 短信来源字段约定

- **发送方**：PDU 中的 TP-OA，可能是手机号、短号码或字母服务号，不能据此识别手机型号或 IMEI。
- **接收卡 / Profile**：短信到达时启用的 eSIM Profile。SIM 初始化会在开启短信上报前读取 ICCID；Profile 列表已加载时使用“名称 + ICCID 尾号”，尚未加载时至少使用“SIM + ICCID 尾号”，从而区分同名 Profile。
- API 新增语义明确的 `receiver` 字段；原 `profile` 字段继续保留为兼容别名。
- 如果模组不支持 `AT+ICCID` 且接收时尚未识别 Profile，记录会明确显示“接收卡未识别”，不会把当前活动 Profile 倒填到历史短信。

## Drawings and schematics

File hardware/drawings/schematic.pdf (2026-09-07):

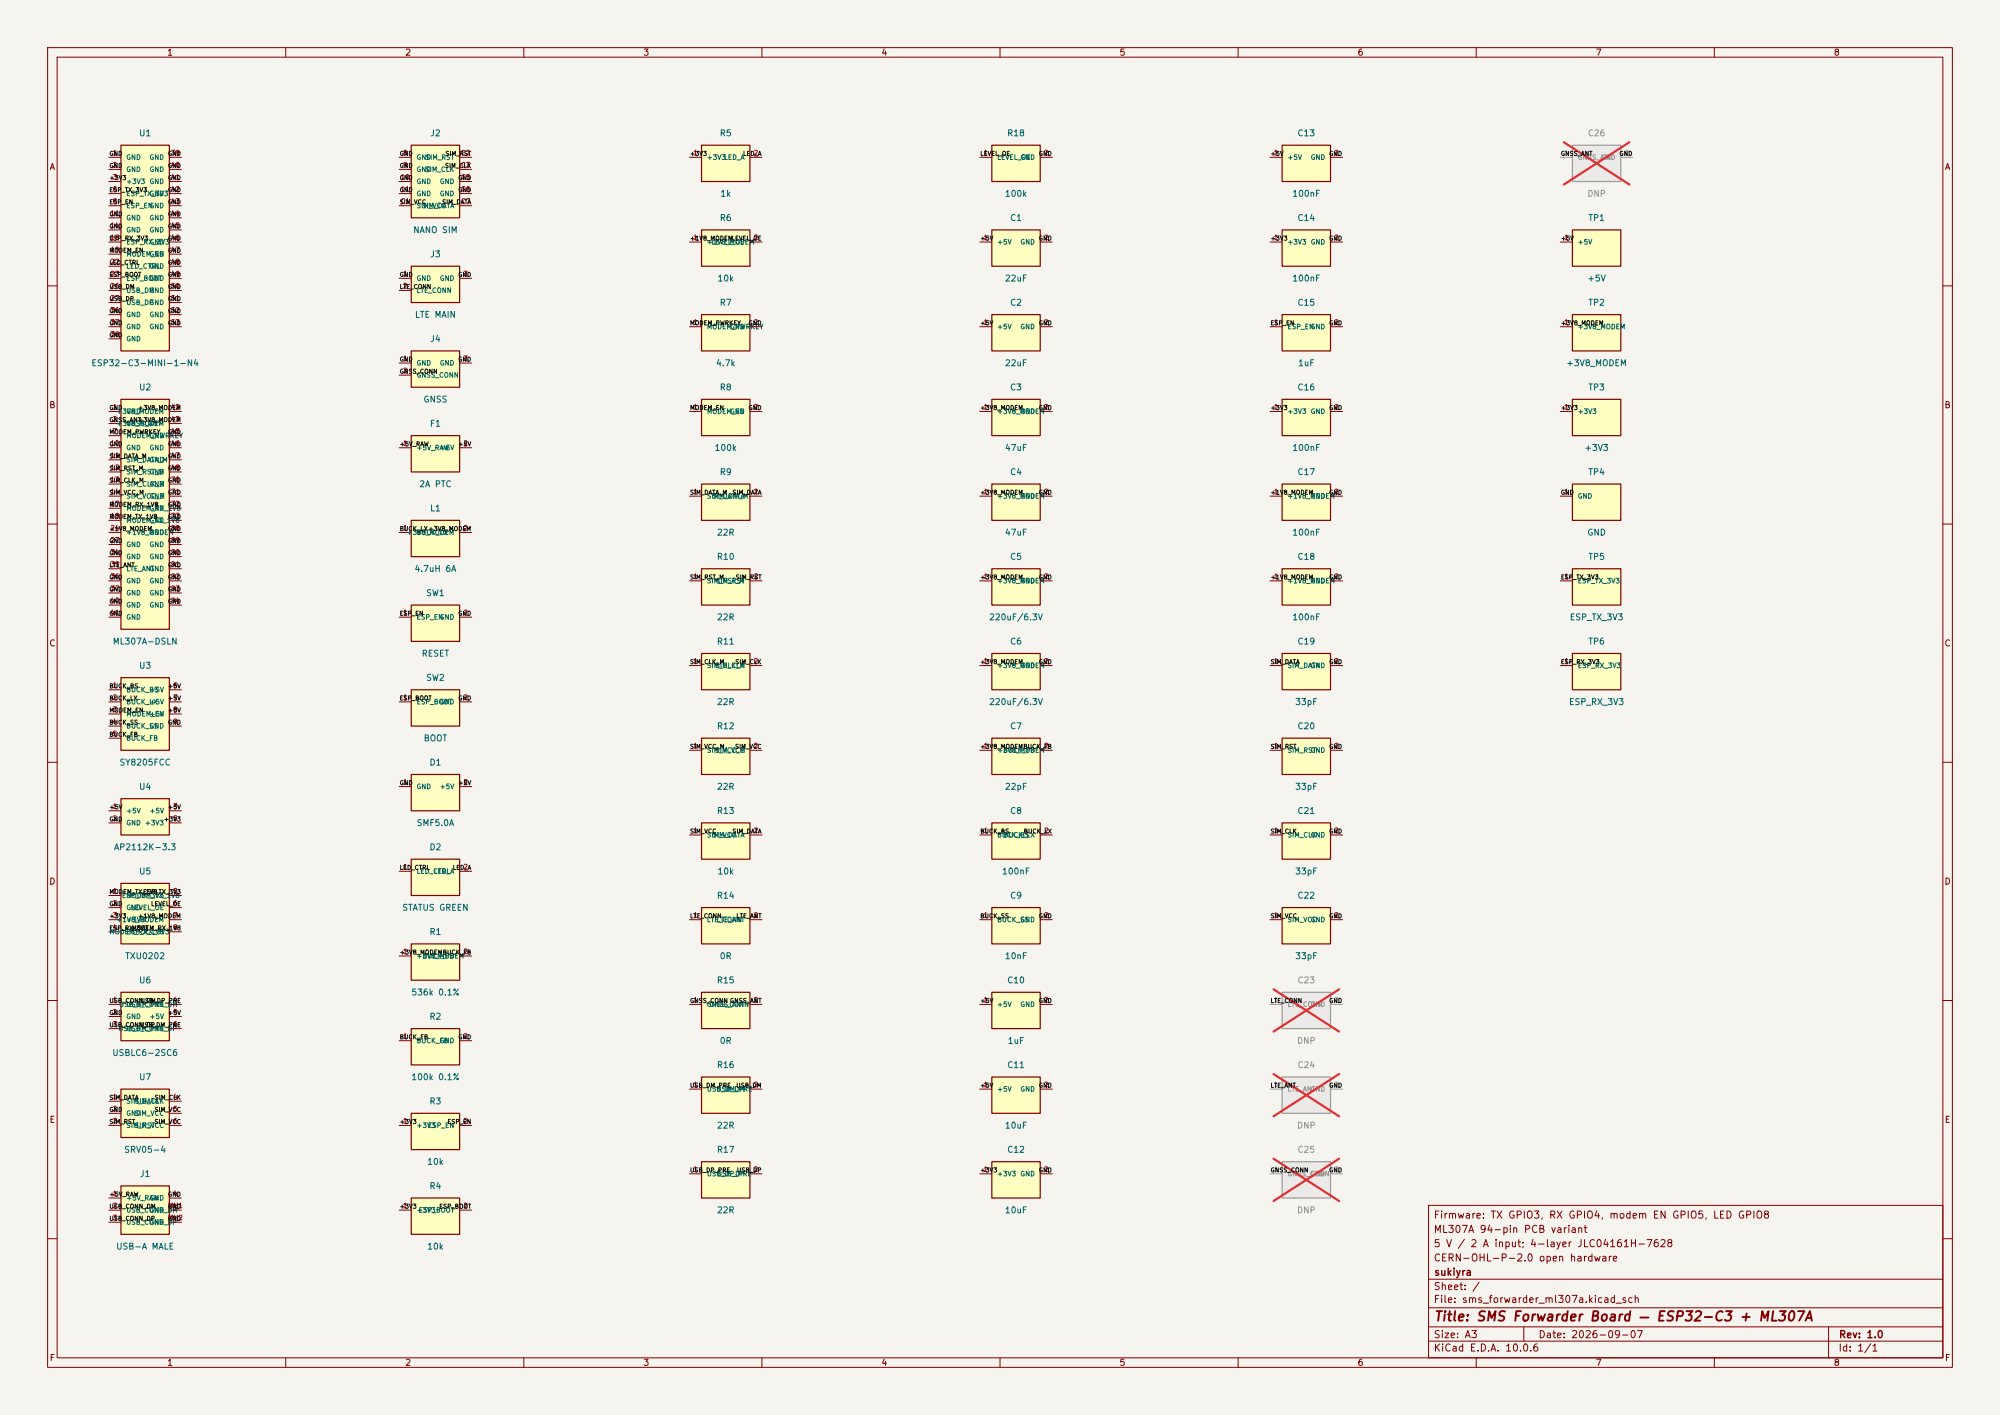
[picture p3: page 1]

Firmware: TX GPIO3, RX GPIO4, modem EN GPIO5, LED GPIO8
ML307A 94-pin PCB variant
5 V / 2 A input; 4-layer JLC04161H-7628
CERN-OHL-P-2.0 open hardware
sukiyra
Sheet: /
File: sms_forwarder_ml307a.kicad_sch
Title: SMS Forwarder Board — ESP32-C3 + ML307A

Size: A3 | Rev: 1.0
KiCad E.D.A. 10.0.6 | Id: 1/1

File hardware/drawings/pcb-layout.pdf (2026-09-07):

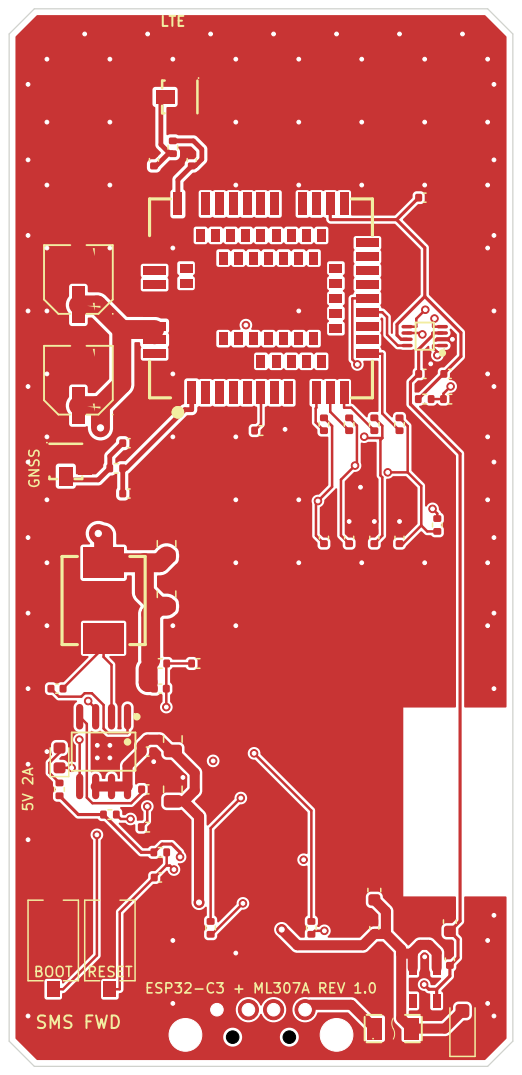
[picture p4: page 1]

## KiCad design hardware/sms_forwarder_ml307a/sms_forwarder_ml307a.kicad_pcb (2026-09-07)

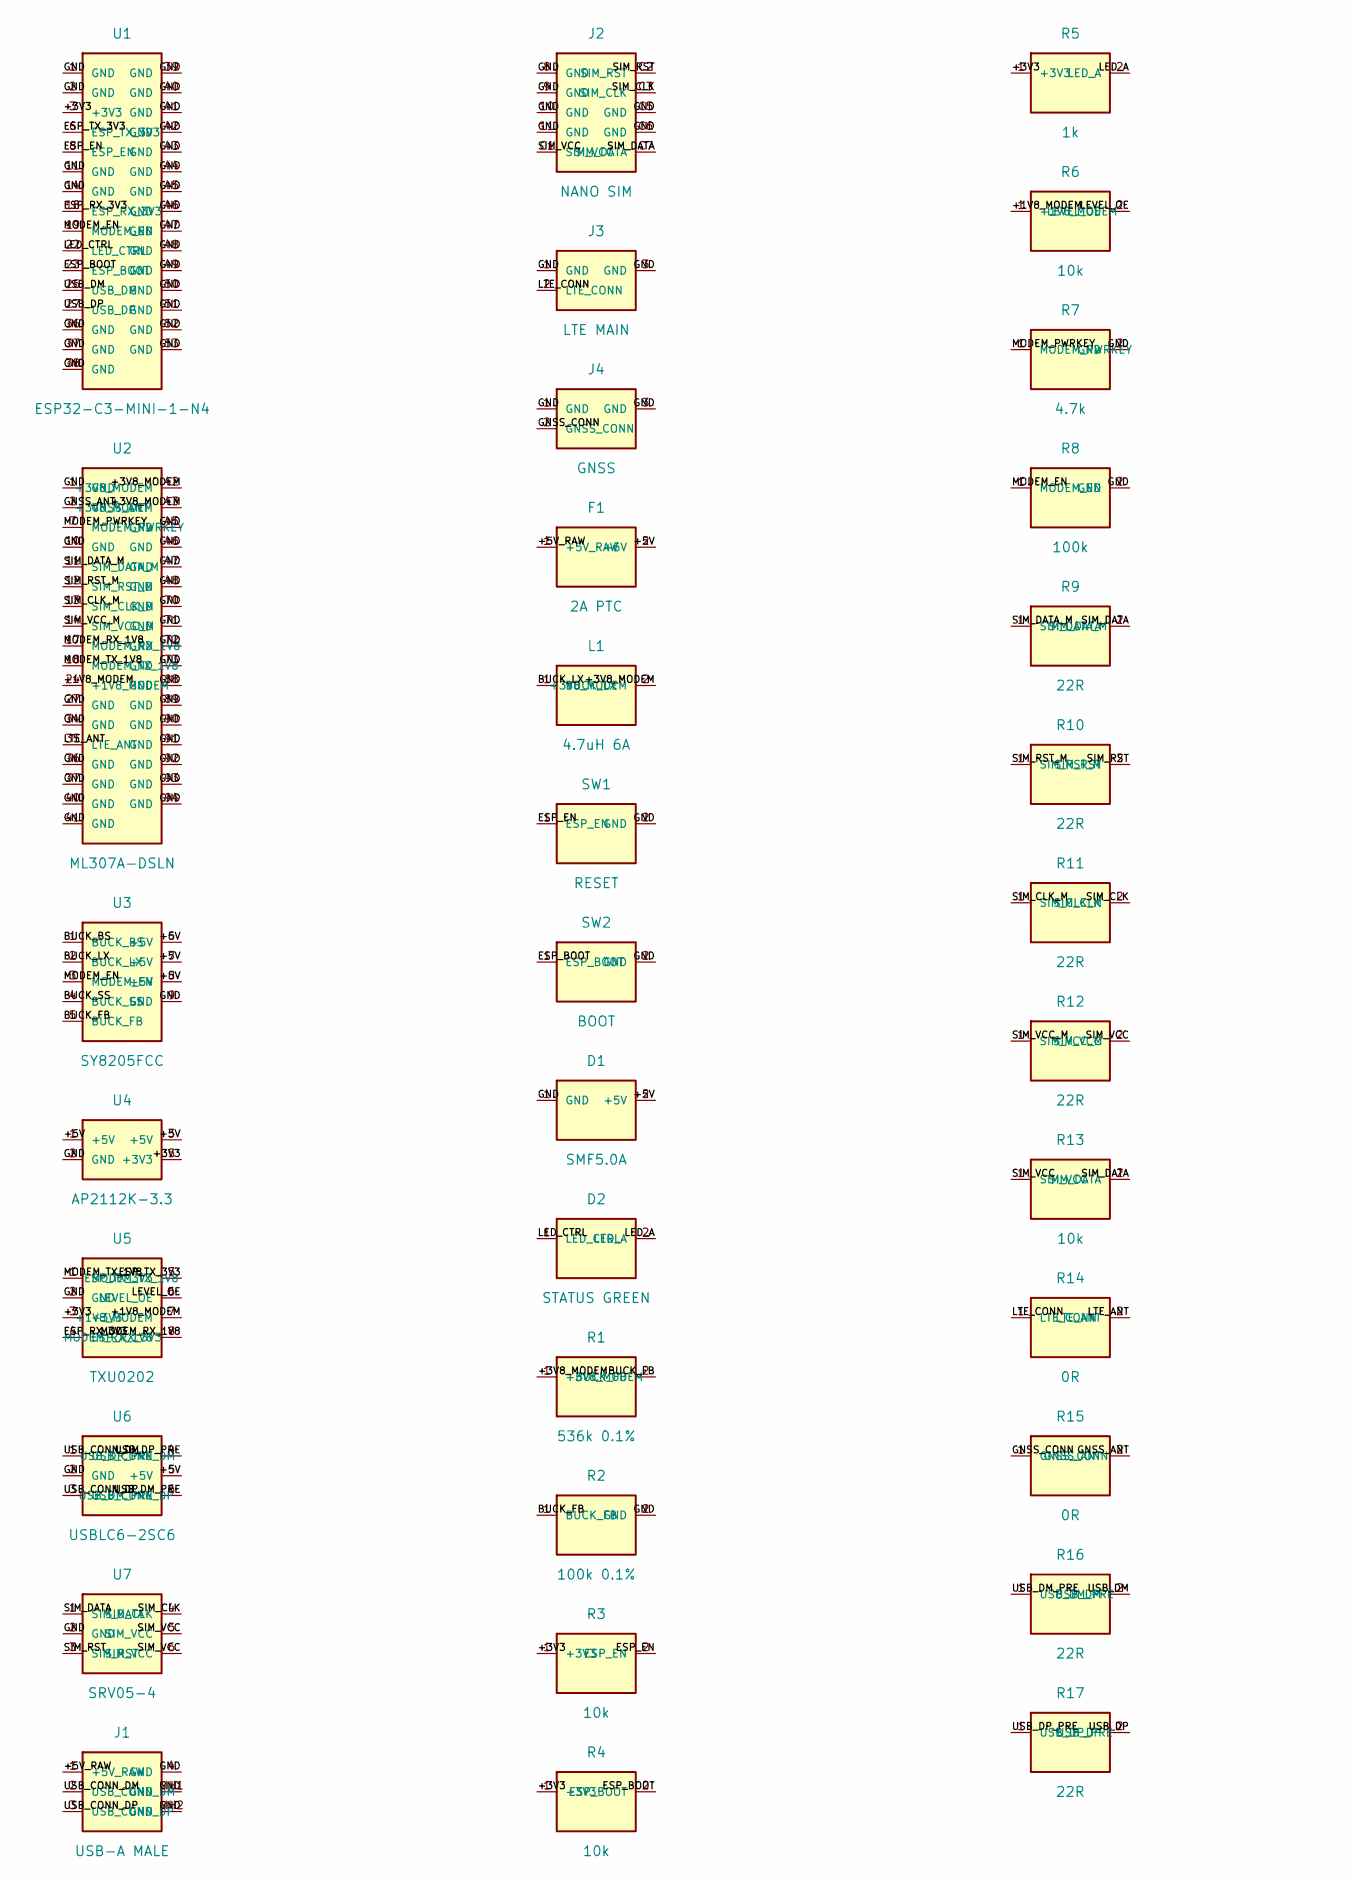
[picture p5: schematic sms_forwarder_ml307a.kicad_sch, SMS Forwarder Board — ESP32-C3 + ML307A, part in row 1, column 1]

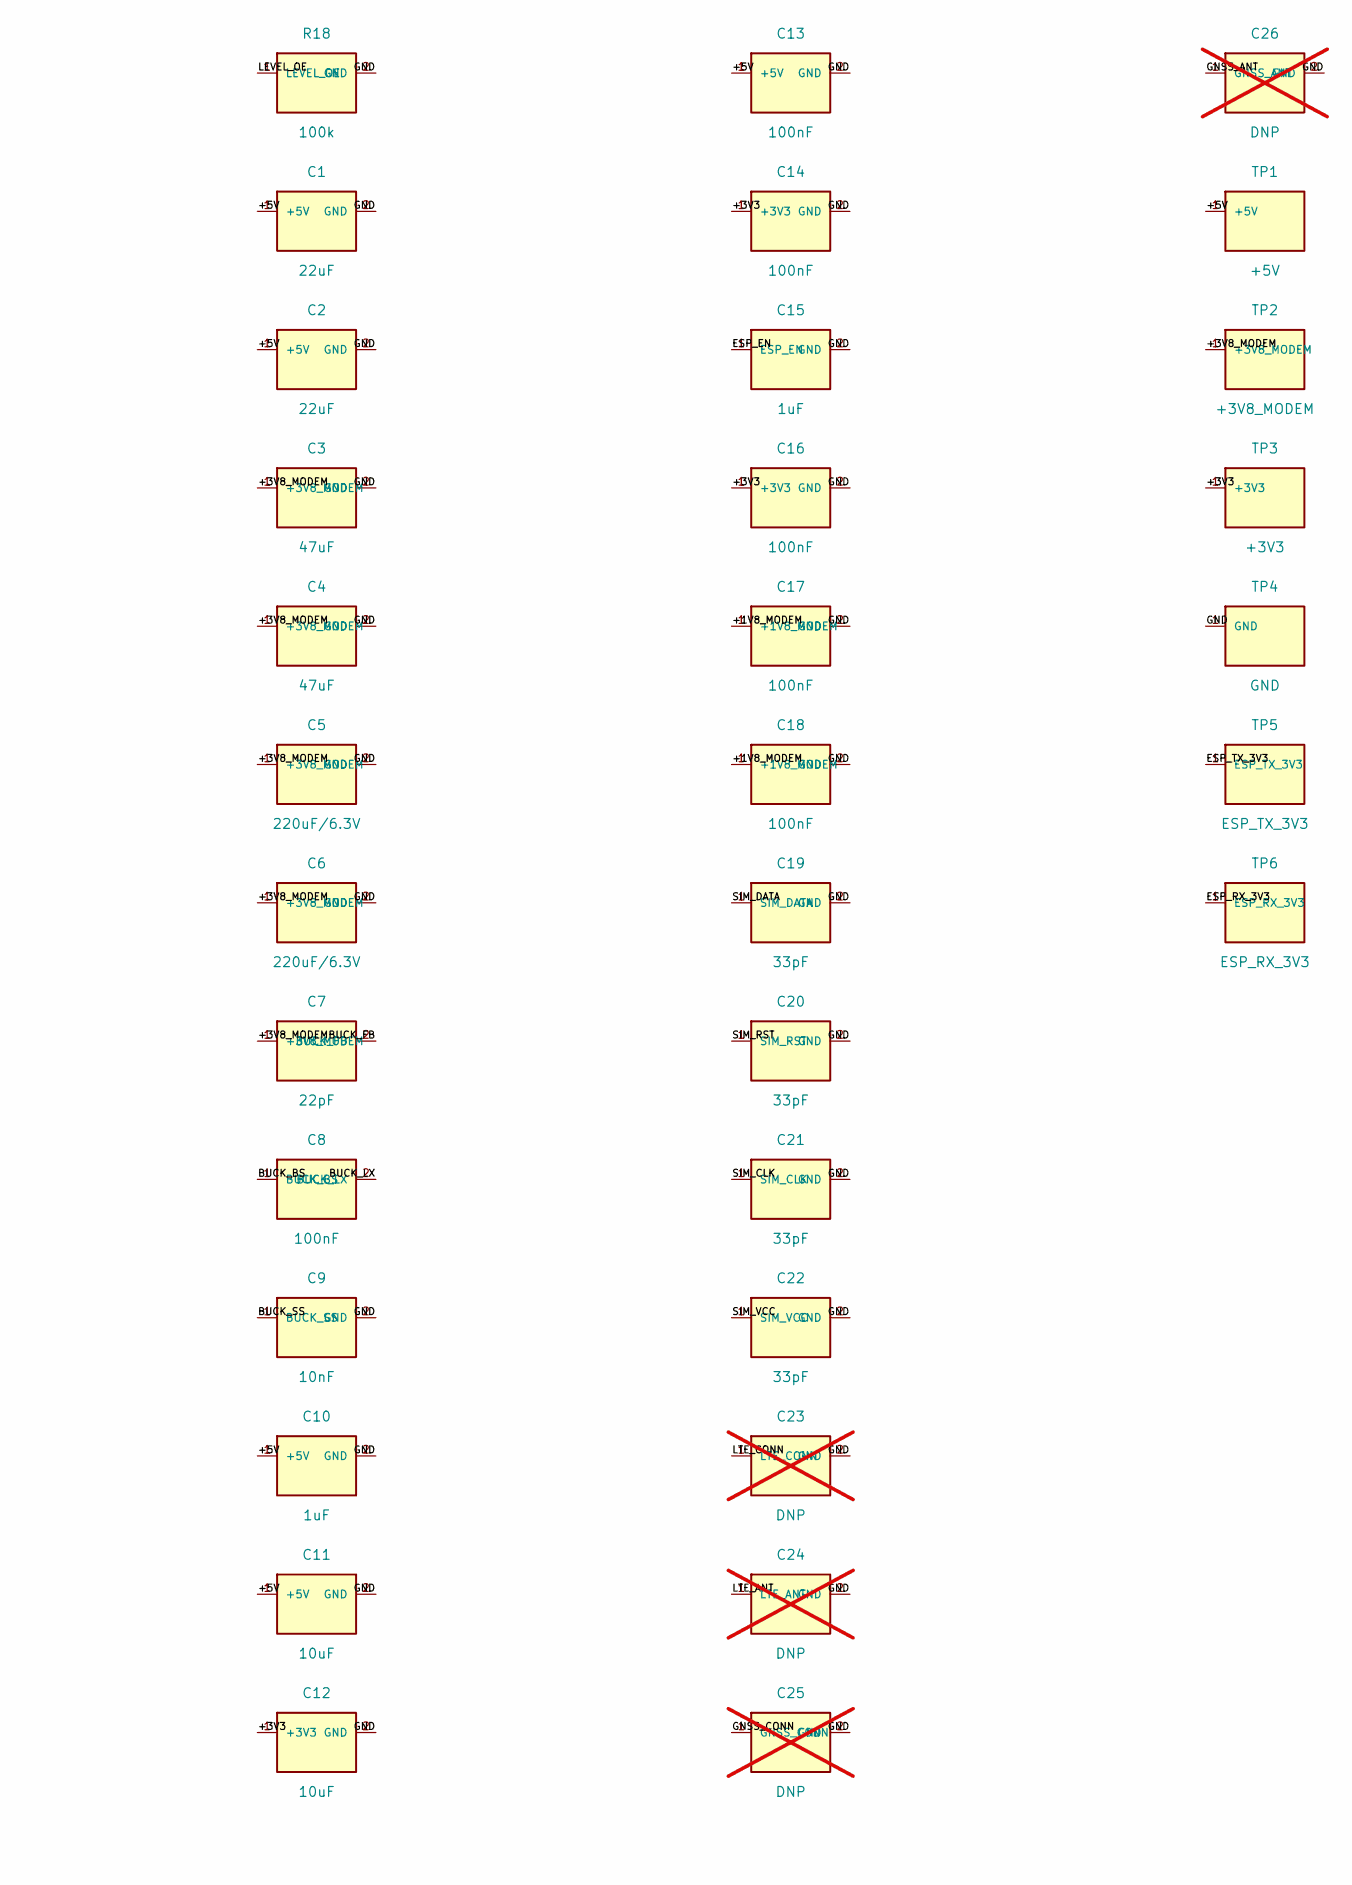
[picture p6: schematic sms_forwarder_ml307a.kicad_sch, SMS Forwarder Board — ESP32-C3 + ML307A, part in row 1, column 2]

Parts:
C1, C2: 22uF; C_0805_2012Metric
C3, C4: 47uF; C_0805_2012Metric
C5, C6: 220uF/6.3V; CAP-SMD_BD5.0-L5.3-W5.3-LS5.7-FD
C7: 22pF; C_0402_1005Metric
C8, C13, C14, C16, C17, C18: 100nF; C_0402_1005Metric
C9: 10nF; C_0402_1005Metric
C10, C15: 1uF; C_0402_1005Metric
C11, C12: 10uF; C_0603_1608Metric
C19, C20, C21, C22: 33pF; C_0402_1005Metric
C23, C24, C25, C26: DNP; C_0402_1005Metric; not fitted
D1: SMF5.0A; D_SOD-123F
D2: STATUS GREEN; LED_0603_1608Metric
F1: 2A PTC; F1206
J1: USB-A MALE; USB-AM-TH_AM90
J2: NANO SIM; SIM-SMD_NANO-SIM-6PIN-1.45H
J3: LTE MAIN; ANT-SMD_UFL-R-SMT-1-10
J4: GNSS; ANT-SMD_UFL-R-SMT-1-10
L1: 4.7uH 6A; IND-SMD_L7.0-W6.6
R1: 536k 0.1%; R_0402_1005Metric
R2: 100k 0.1%; R_0402_1005Metric
R3, R4, R6, R13: 10k; R_0402_1005Metric
R5: 1k; R_0402_1005Metric
R7: 4.7k; R_0402_1005Metric
R8, R18: 100k; R_0402_1005Metric
R9, R10, R11, R12, R16, R17: 22R; R_0402_1005Metric
R14, R15: 0R; R_0402_1005Metric
SW1: RESET; SW_Tactile_SPST_NO_Straight_CK_PTS636Sx25SMTRLFS
SW2: BOOT; SW_Tactile_SPST_NO_Straight_CK_PTS636Sx25SMTRLFS
TP1: +5V; TestPoint_Pad_D1.0mm
TP2: +3V8_MODEM; TestPoint_Pad_D1.0mm
TP3: +3V3; TestPoint_Pad_D1.0mm
TP4: GND; TestPoint_Pad_D1.0mm
TP5: ESP_TX_3V3; TestPoint_Pad_D1.0mm
TP6: ESP_RX_3V3; TestPoint_Pad_D1.0mm
U1: ESP32-C3-MINI-1-N4; WIFIM-SMD_ESP32-C3-MINI-1
U2: ML307A-DSLN; LGA-94_L17.7-W15.8_N706-CA-01-S1
U3: SY8205FCC; SOIC-8_L5.0-W4.0-P1.27-LS6.0-BL-EP2.0
U4: AP2112K-3.3; SOT-25-5_L2.9-W1.6-P0.95-LS2.8-BL
U5: TXU0202; VSSOP-8_L2.3-W2.0-P0.50-LS3.1-BR
U6: USBLC6-2SC6; SOT-23-6_L2.9-W1.6-P0.95-LS2.8-BL
U7: SRV05-4; SOT-23-6_L2.9-W1.6-P0.95-LS2.8-BL

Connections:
+1V8_MODEM: C17.1 (+1V8_MODEM), C18.1 (+1V8_MODEM), R6.1 (+1V8_MODEM), U2.24 (+1V8_MODEM), U5.7 (+1V8_MODEM)
+3V3: C12.1 (+3V3), C14.1 (+3V3), C16.1 (+3V3), R3.1 (+3V3), R4.1 (+3V3), R5.1 (+3V3), TP3.1, U1.3 (+3V3), U4.5 (+3V3), U5.3 (+3V3)
+3V8_MODEM: C3.1 (+3V8_MODEM), C4.1 (+3V8_MODEM), C5.1 (+3V8_MODEM), C6.1 (+3V8_MODEM), C7.1 (+3V8_MODEM), L1.2 (+3V8_MODEM), R1.1 (+3V8_MODEM), TP2.1, U2.42 (+3V8_MODEM), U2.43 (+3V8_MODEM)
+5V: C1.1 (+5V), C2.1 (+5V), C10.1 (+5V), C11.1 (+5V), C13.1 (+5V), D1.2 (+5V), F1.2 (+5V), TP1.1, U3.6 (+5V), U3.7 (+5V), U3.8 (+5V), U4.1 (+5V), U4.3 (+5V), U6.5 (+5V)
+5V_RAW: F1.1 (+5V_RAW), J1.1 (+5V_RAW)
BUCK_BS: C8.1 (BUCK_BS), U3.1 (BUCK_BS)
BUCK_FB: C7.2 (BUCK_FB), R1.2 (BUCK_FB), R2.1 (BUCK_FB), U3.5 (BUCK_FB)
BUCK_LX: C8.2 (BUCK_LX), L1.1 (BUCK_LX), U3.2 (BUCK_LX)
BUCK_SS: C9.1 (BUCK_SS), U3.4 (BUCK_SS)
ESP_BOOT: R4.2 (ESP_BOOT), SW2.1 (ESP_BOOT), U1.23 (ESP_BOOT)
ESP_EN: C15.1 (ESP_EN), R3.2 (ESP_EN), SW1.1 (ESP_EN), U1.8 (ESP_EN)
ESP_RX_3V3: TP6.1, U1.18 (ESP_RX_3V3), U5.4 (ESP_RX_3V3)
ESP_TX_3V3: TP5.1, U1.6 (ESP_TX_3V3), U5.5 (ESP_TX_3V3)
GND: C1.2 (GND), C2.2 (GND), C3.2 (GND), C4.2 (GND), C5.2 (GND), C6.2 (GND), C9.2 (GND), C10.2 (GND), C11.2 (GND), C12.2 (GND), C13.2 (GND), C14.2 (GND), C15.2 (GND), C16.2 (GND), C17.2 (GND), C18.2 (GND), C19.2 (GND), C20.2 (GND), C21.2 (GND), C22.2 (GND), C23.2 (GND), C24.2 (GND), C25.2 (GND), C26.2 (GND), D1.1 (GND), J1.4 (GND), J1.MH1 (GND), J1.MH2 (GND), J2.8 (GND), J2.9 (GND), J2.10 (GND), J2.11 (GND), J2.C5 (GND), J2.C6 (GND), J3.1 (GND), J3.3 (GND), J4.1 (GND), J4.3 (GND), R2.2 (GND), R7.2 (GND), R8.2 (GND), R18.2 (GND), SW1.2 (GND), SW2.2 (GND), TP4.1, U1.1 (GND), U1.2 (GND), U1.11 (GND), U1.14 (GND), U1.36 (GND), U1.37 (GND), U1.38 (GND), U1.39 (GND), U1.40 (GND), U1.41 (GND), U1.42 (GND), U1.43 (GND), U1.44 (GND), U1.45 (GND), U1.46 (GND), U1.47 (GND), U1.48 (GND), U1.49 (GND), U1.50 (GND), U1.51 (GND), U1.52 (GND), U1.53 (GND), U2.1 (GND), U2.10 (GND), U2.27 (GND), U2.34 (GND), U2.36 (GND), U2.37 (GND), U2.40 (GND), U2.41 (GND), U2.45 (GND), U2.46 (GND), U2.47 (GND), U2.48 (GND), U2.70 (GND), U2.71 (GND), U2.72 (GND), U2.73 (GND), U2.88 (GND), U2.89 (GND), U2.90 (GND), U2.91 (GND), U2.92 (GND), U2.93 (GND), U2.94 (GND), U3.9 (GND), U4.2 (GND), U5.2 (GND), U6.2 (GND), U7.2 (GND)
GNSS_ANT: C26.1 (GNSS_ANT), R15.2 (GNSS_ANT), U2.2 (GNSS_ANT)
GNSS_CONN: C25.1 (GNSS_CONN), J4.2 (GNSS_CONN), R15.1 (GNSS_CONN)
LED_A: D2.2 (LED_A), R5.2 (LED_A)
LED_CTRL: D2.1 (LED_CTRL), U1.22 (LED_CTRL)
LEVEL_OE: R6.2 (LEVEL_OE), R18.1 (LEVEL_OE), U5.6 (LEVEL_OE)
LTE_ANT: C24.1 (LTE_ANT), R14.2 (LTE_ANT), U2.35 (LTE_ANT)
LTE_CONN: C23.1 (LTE_CONN), J3.2 (LTE_CONN), R14.1 (LTE_CONN)
MODEM_EN: R8.1 (MODEM_EN), U1.19 (MODEM_EN), U3.3 (MODEM_EN)
MODEM_PWRKEY: R7.1 (MODEM_PWRKEY), U2.7 (MODEM_PWRKEY)
MODEM_RX_1V8: U2.17 (MODEM_RX_1V8), U5.8 (MODEM_RX_1V8)
MODEM_TX_1V8: U2.18 (MODEM_TX_1V8), U5.1 (MODEM_TX_1V8)
SIM_CLK: C21.1 (SIM_CLK), J2.C3 (SIM_CLK), R11.2 (SIM_CLK), U7.4 (SIM_CLK)
SIM_CLK_M: R11.1 (SIM_CLK_M), U2.13 (SIM_CLK_M)
SIM_DATA: C19.1 (SIM_DATA), J2.C7 (SIM_DATA), R9.2 (SIM_DATA), R13.2 (SIM_DATA), U7.1 (SIM_DATA)
SIM_DATA_M: R9.1 (SIM_DATA_M), U2.11 (SIM_DATA_M)
SIM_RST: C20.1 (SIM_RST), J2.C2 (SIM_RST), R10.2 (SIM_RST), U7.3 (SIM_RST)
SIM_RST_M: R10.1 (SIM_RST_M), U2.12 (SIM_RST_M)
SIM_VCC: C22.1 (SIM_VCC), J2.C1 (SIM_VCC), R12.2 (SIM_VCC), R13.1 (SIM_VCC), U7.5 (SIM_VCC), U7.6 (SIM_VCC)
SIM_VCC_M: R12.1 (SIM_VCC_M), U2.14 (SIM_VCC_M)
USB_CONN_DM: J1.2 (USB_CONN_DM), U6.1 (USB_CONN_DM)
USB_CONN_DP: J1.3 (USB_CONN_DP), U6.3 (USB_CONN_DP)
USB_DM: R16.2 (USB_DM), U1.26 (USB_DM)
USB_DM_PRE: R16.1 (USB_DM_PRE), U6.6 (USB_DM_PRE)
USB_DP: R17.2 (USB_DP), U1.27 (USB_DP)
USB_DP_PRE: R17.1 (USB_DP_PRE), U6.4 (USB_DP_PRE)

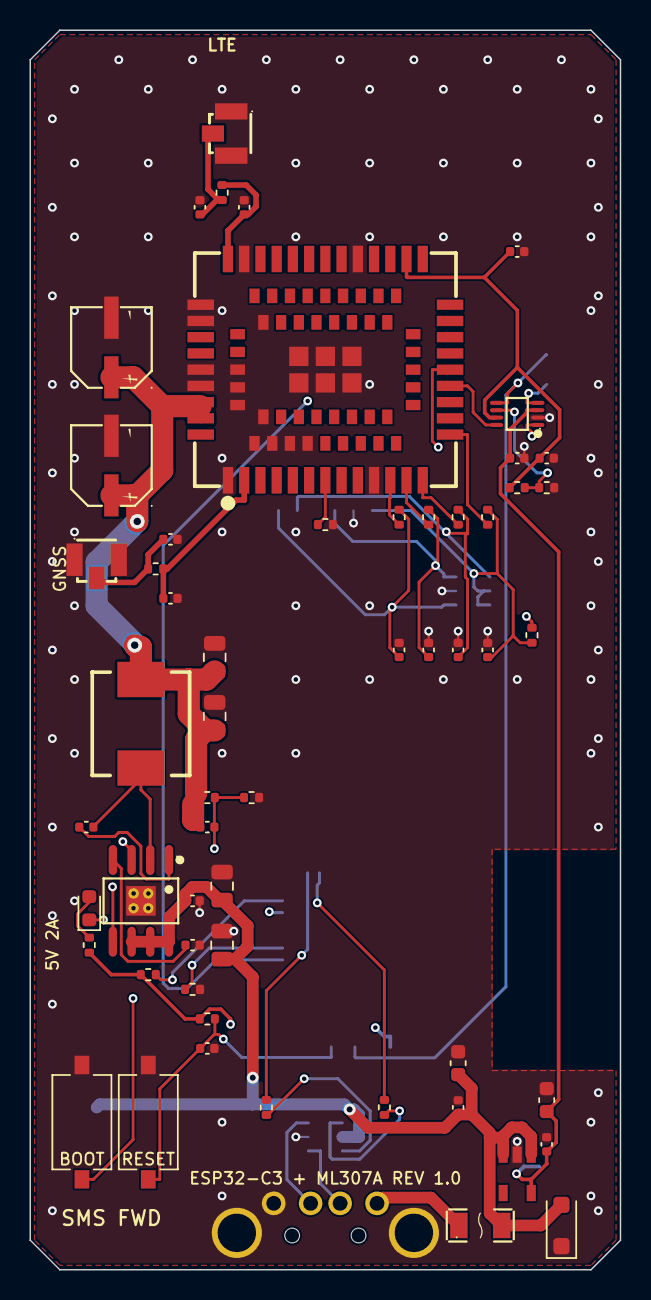
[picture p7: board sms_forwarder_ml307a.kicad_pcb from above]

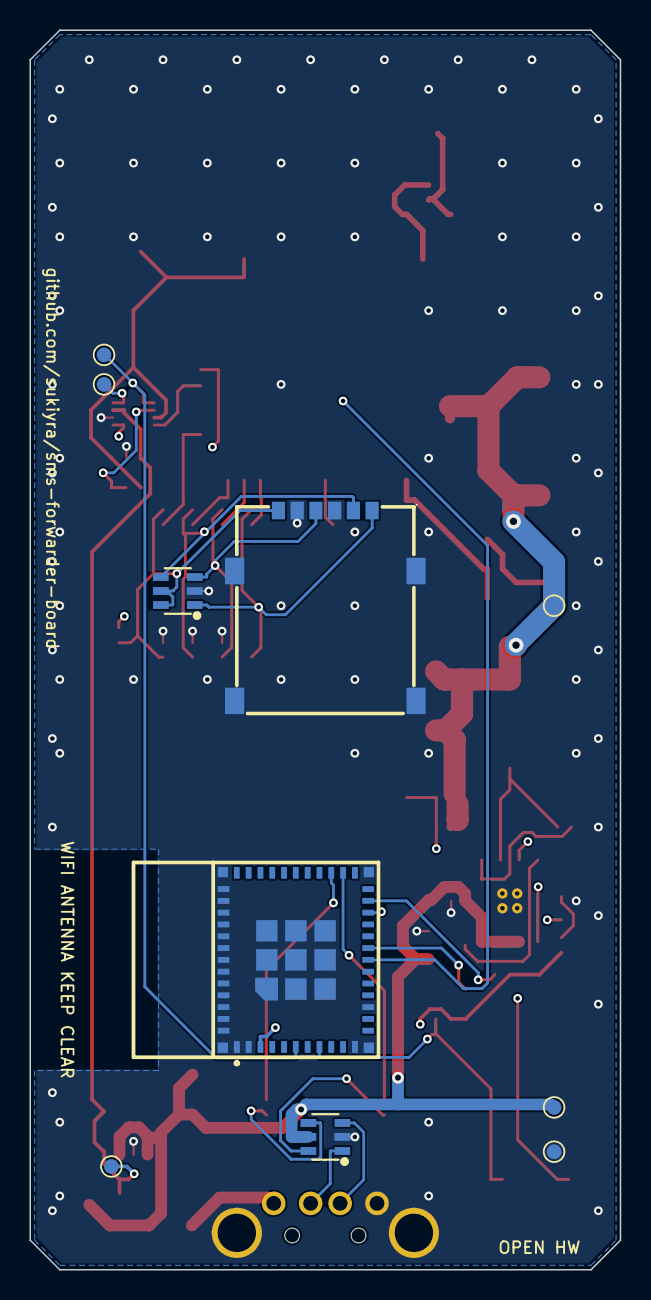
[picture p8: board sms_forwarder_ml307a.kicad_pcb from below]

Board: 4 copper layers, 40.0 x 84.0 mm, 67 parts (10 on the bottom side), 39 nets.

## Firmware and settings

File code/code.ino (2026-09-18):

#include "globals.h"
#include "config.h"
#include "web_handlers.h"
#include <HTTPClient.h>
#include "modem.h"
#include "push.h"
#include "sms_process.h"
#include "auth.h"
#include "api_handlers.h"
#include "sms_store.h"
#include "esim_manager.h"
#include "operator_manager.h"
#include "sim_manager.h"
#include "factory_serial.h"
#include "ota_manager.h"
#include "discovery.h"

void setup() {
  pinMode(LED_BUILTIN, OUTPUT);
  digitalWrite(LED_BUILTIN, HIGH);
  Serial.begin(115200);
  // 缩短初始化延时，WiFi连接会处理自己的超时
  delay(200);
  Serial1.setRxBufferSize(MODEM_RX_BUFFER_SIZE);
  Serial1.begin(115200, SERIAL_8N1, RXD, TXD);
  while (Serial1.available()) Serial1.read();
  modemPowerCycle();
  while (Serial1.available()) Serial1.read();
  initConcatBuffer();
  loadConfig();
  configValid = isConfigValid();
  if (!smsStoreBegin()) {
    logCaptureLn(String("⚠️ 短信持久化存储初始化失败"));
  }
  otaManagerBegin();

  // ---- HTTP 服务先行启动,保证任意 WiFi 状态下都可访问管理台 ----
  // WebServer 依赖 WiFi 协议栈的事件队列,必须先初始化 WiFi 再起服务
  // persistent(false): 凭据只由本固件 NVS 管理,防止 esp 自动重连旧网络干扰热点
  WiFi.persistent(false);
  WiFi.mode(WIFI_STA);
  authBegin();
  server.on("/", HTTP_GET, handleRoot);
  server.on("/tools", HTTP_GET, handleRoot);
  server.on("/sms", HTTP_GET, handleRoot);
  server.on("/query", handleQuery);
  server.on("/at", HTTP_POST, handleATCommand);
  server.on("/log", HTTP_GET, handleLog);
  server.on("/modem", handleModem);
  server.on("/wifi", HTTP_POST, handleWifi);
  server.on("/ping", HTTP_POST, handlePing);
  registerApiRoutes();
  server.begin();
  logCaptureLn(String("HTTP服务器已启动"));

  // ---- WiFi:依次尝试主备网络,全部失败则开启配置热点 ----
  if (wifiConnectAll()) {
    logCaptureLn(String("wifi已连接"));
    logCapture(String("IP地址: "));
    logCaptureLn(WiFi.localIP().toString());
    logCapture(String("信号强度(RSSI): "));
    logCaptureLn(String(WiFi.RSSI()) + " dBm");
  } else {
    wifiStartAp();
  }
  discoveryBegin();

  // ---- NTP 时间同步 ----
  logCaptureLn(String("正在同步NTP时间..."));
  configTime(0, 0, "ntp.ntsc.ac.cn", "ntp.aliyun.com", "pool.ntp.org");
  unsigned long ntpStartedAt = millis();
  while (time(nullptr) < 100000 && millis() - ntpStartedAt < 5000) {
    delay(25);
    server.handleClient();
  }
  if (time(nullptr) >= 100000) {
    logCaptureLn(String("NTP时间同步成功"));
    time_t now = time(nullptr);
    logCapture(String("当前UTC时间戳: "));
    logCaptureLn(String(now));
  } else {
    logCaptureLn(String("NTP时间同步失败，将使用设备时间"));
  }

  ssl_client.setInsecure();
  digitalWrite(LED_BUILTIN, LOW);

  // ---- 启动通知（网页已可用，发邮件不会影响用户访问） ----
  if (configValid) {
    logCaptureLn(String("配置有效，发送启动通知..."));
    String subject = "短信转发器已启动";
    String body = "设备已启动\n设备地址: " + getDeviceUrl();
    sendEmailNotification(subject.c_str(), body.c_str());
  }

  // ---- 模组初始化（较慢，但网页已可访问） ----
  modemInit();
  esimManagerBegin();
  simManagerBegin();
  operatorManagerBegin();

  // Confirm a newly installed image only after the complete application
  // initialization path succeeds. A crash or watchdog reset before here
  // leaves the image pending so the bootloader restores the previous slot.
  otaManagerConfirmBoot();
}

void loop() {
  discoveryLoop();
  otaManagerLoop();
  if (otaManagerBusy()) {
    // Version checks and downloads are exclusive maintenance operations.
    // Requests are acknowledged before work starts, and the inactive OTA
    // slot remains non-bootable until download and SHA-256 verification pass.
    server.handleClient();
    delay(1);
    return;
  }
  // Drain long COPS responses before serving HTTP so the UART ring cannot
  // overflow while a network scan is returning several kilobytes at once.
  operatorManagerLoop();
  // Only drain an already active SIM transaction before HTTP. New periodic
  // probes are started after serving HTTP so the 3-second status poll cannot
  // repeatedly observe a short CPIN transaction as a permanently busy modem.
  if (simManagerIsBusy()) simManagerLoop();
  if (smsStoredMessageIsBusy()) smsStoredMessageLoop();
  server.handleClient();
  static bool configWarningPrinted = false;
  if (!configValid && !configWarningPrinted) {
    configWarningPrinted = true;
    logCaptureLn(String("⚠️ 请访问 " + getDeviceUrl() + " 配置系统参数"));
  }
  checkConcatTimeout();
  checkSmsReceiveTimeout();
  operatorManagerLoop();
  simManagerLoop();
  smsStoredMessageLoop();
  if (!operatorManagerIsBusy() && !simManagerIsBusy() && !smsStoredMessageIsBusy()) {
    esimManagerLoop();
  }
  if (!esimIsBusy() && !operatorManagerIsBusy() && !simManagerIsBusy() &&
      !smsStoredMessageIsBusy()) {
    factorySerialLoop();
    checkSerial1URC();
  }
  // Web requests only enqueue outbound SMS so the browser gets an immediate
  // response. Run the modem transaction after URCs and SIM work are drained.
  processPendingWebSms();
  if (schedulerTickDue() && !pendingWebSmsBusy()) {
    checkCustomTasks();
  }
  wifiMaintenanceLoop();
  delay(1);
}

// 自定义任务:按小时间隔定时执行 重启/AT/HTTP
static void runCustomTask(int i) {
  const CustomTask &t = config.tasks[i];
  if (t.type == TASK_RESTART) {
    logCaptureLn(String("自定义任务") + String(i + 1) + ": 定时重启设备");
    configRecordTaskRun(i, time(nullptr));
    delay(500);
    ESP.restart();
  } else if (t.type == TASK_AT) {
    logCaptureLn(String("自定义任务") + String(i + 1) + ": 执行 AT: " + t.param);
    String resp = sendATCommand(t.param.c_str(), 8000);
    logCaptureLn(String("任务AT响应: ") + resp.substring(0, 180));
  } else if (t.type == TASK_HTTP) {
    logCaptureLn(String("自定义任务") + String(i + 1) + ": " + String(t.httpMethod == 1 ? "POST " : "GET ") + t.param);
    if (WiFi.status() != WL_CONNECTED) {
      logCaptureLn(String("任务HTTP跳过: WiFi未连接"));
      return;
    }
    HTTPClient http;
    http.begin(t.param.c_str());
    http.setTimeout(15000);
    int from = 0;
    while (from >= 0 && from < (int)t.headers.length()) {
      int eol = t.headers.indexOf('\n', from);
      String line = t.headers.substring(from, eol < 0 ? t.headers.length() : eol);
      line.trim();
      int colon = line.indexOf(':');
      if (colon > 0) {
        String name = line.substring(0, colon);
        name.trim();
        String value = line.substring(colon + 1);
        value.trim();
        http.addHeader(name.c_str(), value.c_str(), false);
      }
      from = eol < 0 ? t.headers.length() : eol + 1;
    }
    int code = t.httpMethod == 1 ? http.POST(t.body) : http.GET();
    logCaptureLn(String("任务HTTP响应码: ") + String(code));
    http.end();
  }
}

// 日历模式按本地时区 UTC+8 计算,与网页端展示一致
constexpr long kLocalTzOffsetSec = 8 * 3600L;

static uint8_t daysInMonth(int year, int mon) {
  static const uint8_t d[] = {31, 28, 31, 30, 31, 30, 31, 31, 30, 31, 30, 31};
  if (mon == 1 && ((year % 4 == 0 && year % 100 != 0) || year % 400 == 0)) return 29;
  return d[mon];
}

// 返回最近一个已到达的计划时刻(本地帧);非日历模式返回 0
static time_t lastScheduledAt(const CustomTask &t, time_t nowLocal, struct tm &lt) {
  time_t dayStart = nowLocal - (lt.tm_hour * 3600 + lt.tm_min * 60 + lt.tm_sec);
  if (t.mode == 1) return dayStart + t.hour * 3600 + t.minute * 60;
  if (t.mode == 2) {
    int back = (lt.tm_wday - t.weekday + 7) % 7;
    return dayStart - (time_t)back * 86400 + t.hour * 3600 + t.minute * 60;
  }
  if (t.mode == 3) {
    uint8_t dom = t.dayOfMonth < 1 ? 1 : t.dayOfMonth;
    uint8_t dim = daysInMonth(lt.tm_year + 1900, lt.tm_mon);
    if (dom > dim) dom = dim;
    time_t monthStart = dayStart - (time_t)(lt.tm_mday - 1) * 86400;
    return monthStart + (time_t)(dom - 1) * 86400 + t.hour * 3600 + t.minute * 60;
  }
  return 0;
}

static void checkCustomTasks() {
  time_t now = time(nullptr);
  if (now < 100000) return;
  for (int i = 0; i < MAX_CUSTOM_TASKS; i++) {
    const CustomTask &t = config.tasks[i];
    if (t.type == TASK_NONE) continue;
    if (t.mode == 0 && t.intervalSeconds == 0) continue;
    if (t.type != TASK_HTTP) {
      if (esimIsBusy() || operatorManagerIsBusy() || simManagerIsBusy() ||
          smsStoredMessageIsBusy() || modemIsBusy()) {
        continue;
      }
    }
    uint32_t last = configTaskLastRun(i);
    bool due = false;
    if (t.mode == 0) {
      due = (last == 0) || ((uint32_t)now - last >= t.intervalSeconds);
    } else {
      time_t local = now + kLocalTzOffsetSec;
      struct tm lt;
      gmtime_r(&local, &lt);
      time_t at = lastScheduledAt(t, local, lt);
      if (at > 0) due = (local >= at) && (last == 0 || (time_t)last + kLocalTzOffsetSec < at);
    }
    if (!due) continue;
    configRecordTaskRun(i, (uint32_t)now);
    runCustomTask(i);
  }
}

static unsigned long schedulerLastTick = 0;
static bool schedulerTickDue() {
  if (millis() - schedulerLastTick < 60000) return false;
  schedulerLastTick = millis();
  return true;
}

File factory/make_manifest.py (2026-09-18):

#!/usr/bin/env python3
"""Copy Arduino output and create a hash-verified production bundle."""

from __future__ import annotations

import argparse
import hashlib
import json
import re
import shutil
import struct
import subprocess
from datetime import datetime, timezone
from pathlib import Path


IMAGE_LAYOUT = (
    ("0x0", "code.ino.bootloader.bin"),
    ("0x8000", "code.ino.partitions.bin"),
    ("0xe000", "boot_app0.bin"),
    ("0x10000", "code.ino.bin"),
)

PARTITION_ENTRY = struct.Struct("<HBBII16sI")
EXPECTED_PARTITIONS = {
    "nvs": (0x01, 0x02, 0x9000, 0x5000),
    "otadata": (0x01, 0x00, 0xE000, 0x2000),
    "app0": (0x00, 0x10, 0x10000, 0x1E0000),
    "app1": (0x00, 0x11, 0x1F0000, 0x1E0000),
    "spiffs": (0x01, 0x82, 0x3D0000, 0x20000),
    "coredump": (0x01, 0x03, 0x3F0000, 0x10000),
}


def file_hash(path: Path) -> str:
    return hashlib.sha256(path.read_bytes()).hexdigest()


def parse_partition_table(payload: bytes) -> dict[str, tuple[int, int, int, int]]:
    partitions = {}
    for cursor in range(0, len(payload) - PARTITION_ENTRY.size + 1, PARTITION_ENTRY.size):
        magic, part_type, subtype, offset, size, raw_label, _flags = PARTITION_ENTRY.unpack_from(
            payload, cursor
        )
        if magic in (0xFFFF, 0xEBEB):
            break
        if magic != 0x50AA:
            raise RuntimeError(f"分区表条目损坏：offset 0x{cursor:x}, magic 0x{magic:04x}")
        label = raw_label.split(b"\0", 1)[0].decode("ascii", "strict")
        if not label or label in partitions:
            raise RuntimeError(f"分区表标签无效或重复：{label!r}")
        partitions[label] = (part_type, subtype, offset, size)
    return partitions


def validate_partition_table(path: Path) -> None:
    partitions = parse_partition_table(path.read_bytes())
    for label, expected in EXPECTED_PARTITIONS.items():
        actual = partitions.get(label)
        if actual != expected:
            raise RuntimeError(
                f"分区表不符合量产要求：{label} 应为 {expected}，实际为 {actual}"
            )


def source_version(repo: Path) -> str:
    text = (repo / "code" / "globals.h").read_text(encoding="utf-8")
    match = re.search(r'#define\s+FIRMWARE_VERSION\s+"([^"]+)"', text)
    if not match:
        raise RuntimeError("无法从 code/globals.h 读取固件版本")
    return match.group(1)


def git_commit(repo: Path) -> str:
    try:
        return subprocess.check_output(
            ["git", "rev-parse", "HEAD"], cwd=repo, text=True, stderr=subprocess.DEVNULL
        ).strip()
    except (OSError, subprocess.CalledProcessError):
        return "unknown"


def build_manifest(repo: Path, build: Path, output: Path) -> dict:
    output.mkdir(parents=True, exist_ok=True)
    images = []
    merged = build / "code.ino.merged.bin"
    for offset, filename in IMAGE_LAYOUT:
        source = build / filename
        target = output / filename
        if source.is_file():
            shutil.copy2(source, target)
        elif filename == "boot_app0.bin" and merged.is_file():
            # Arduino CLI does not always copy this common image to --output-dir.
            # The merged image already contains it at 0xe000.
            with merged.open("rb") as payload:
                payload.seek(0xE000)
                target.write_bytes(payload.read(0x2000))
        else:
            raise RuntimeError(f"Arduino 编译产物缺失：{source}")
        images.append(
            {"offset": offset, "file": filename, "size": target.stat().st_size, "sha256": file_hash(target)}
        )
    if merged.is_file():
        shutil.copy2(merged, output / merged.name)
    validate_partition_table(output / "code.ino.partitions.bin")
    manifest = {
        "schema": 1,
        "product": "sms-forwarder-board",
        "version": source_version(repo),
        "sourceCommit": git_commit(repo),
        "builtAt": datetime.now(timezone.utc).isoformat(timespec="seconds"),
        "chip": "esp32c3",
        "flashSize": "4MB",
        "fqbn": "esp32:esp32:makergo_c3_supermini",
        "partitionScheme": "dual_ota_4mb",
        "otaCapable": True,
        "storage": {"type": "littlefs", "offset": "0x3d0000", "size": 131072},
        "supportedModems": ["ML307A", "ML307C", "ML307R", "ML307Y"],
        "images": images,
    }
    (output / "manifest.json").write_text(
        json.dumps(manifest, ensure_ascii=False, indent=2) + "\n", encoding="utf-8"
    )
    return manifest


def main() -> int:
    parser = argparse.ArgumentParser()
    parser.add_argument("build", type=Path)
    parser.add_argument("output", type=Path)
    parser.add_argument("--repo", type=Path, default=Path(__file__).resolve().parents[1])
    args = parser.parse_args()
    manifest = build_manifest(args.repo.resolve(), args.build.resolve(), args.output.resolve())
    print(json.dumps(manifest, ensure_ascii=False))
    return 0


if __name__ == "__main__":
    raise SystemExit(main())

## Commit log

2026-09-06 feat: launch SMS Forwarder Board
2026-09-06 fix: clear recovered network operation state
    [operator_manager.cpp]
2026-09-06 fix: display notification times in Beijing timezone
    [sms_process.cpp]
2026-09-07 feat: publish ML307A open hardware design
    [BOM_Full.csv, BOM_JLCPCB.csv, SMS-Forwarder-BOM.xlsx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]
2026-09-18 fix: allow production testing without a SIM
    [production_tool.py]
2026-09-18 feat: add verified OTA updates with rollback
    [partitions.csv]
2026-09-18 feat: add secure LAN device discovery tool
2026-09-18 fix: restore LittleFS in OTA partition layout
    [partitions.csv]
2026-09-18 fix: reserve reliable flash storage partitions
    [partitions.csv]
2026-09-18 feat: add device health telemetry
